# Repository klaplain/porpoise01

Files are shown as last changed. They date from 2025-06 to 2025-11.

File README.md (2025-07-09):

# UnderwaterAcoustics
This is the code required for the Underwater Acoustics STM32 Acquisition SubSystem that works with the Porpoise01 board and the Raspberry Pi

main.c contains the necessary code to acquire an analog signal sampling at about 700kHz and storing the result to a .DAT file that contains the analog values.  Although the file has a WAV file header, the values are 16 bit unsigned values so the DAT file needs to be post-processed to convert it to a WAV file.  This post-processing is done when saving to the raspberry pi.

*.ioc contains all the necessary CubeIDE configuration data

uw_acoust_client.py is the app that runs on the raspberry pi and controls the Seeed STM32 acquisition system

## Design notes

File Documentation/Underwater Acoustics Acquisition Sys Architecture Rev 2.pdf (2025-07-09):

The Underwater Acoustics Acquisition System is based on an STM32H7x board that is responsible for the hydrophone analog signal acquisition and storing the recorded values on an SD card on the STM board. The STM board is under the control of a Raspberry Pi that has a GUI which the operator uses to control the acquisition

The Raspberry Pi communicates commands to the STM32 using an SPI interface. The STM32 executes the requested command and, if required, returns data to the Raspberry Pi.

The STM32 board also has a serial port through which diagnostics messages are sent during normal operation

The User Interface looks like this and is served up by the Raspberry Pi using a Flask Server

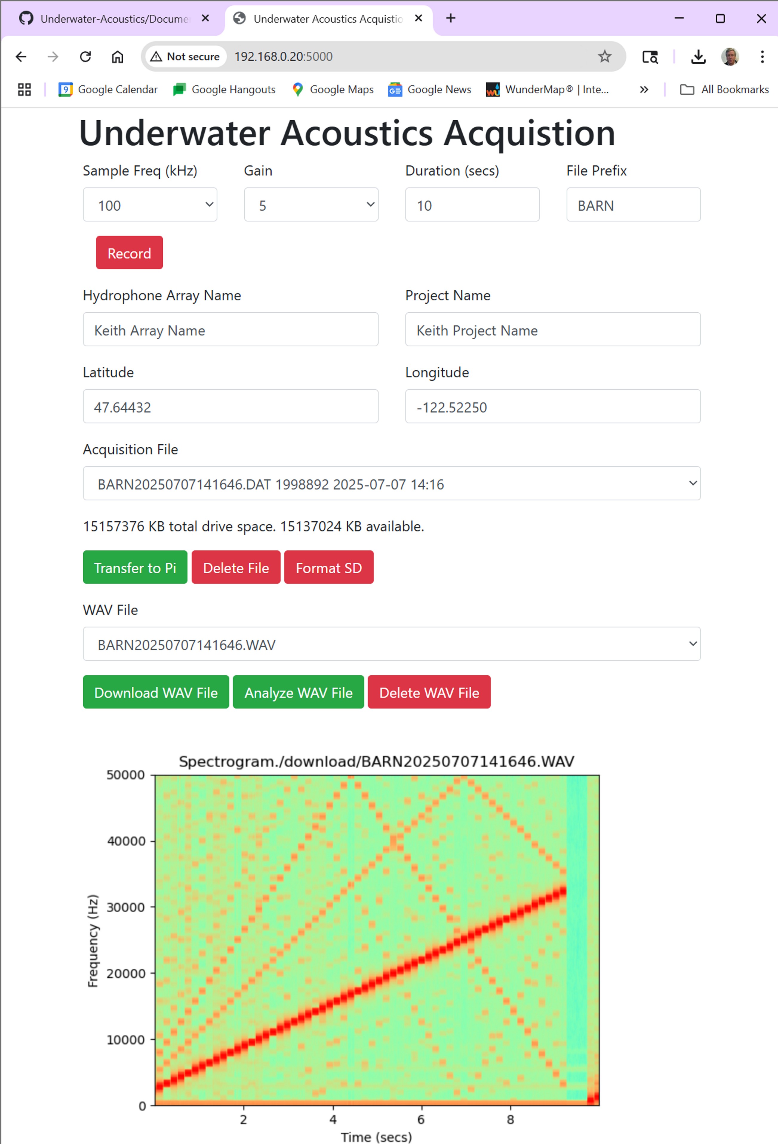
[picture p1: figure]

The user defines the parameters for the upcoming recording including duration, sampling frequency and gain.
The user can select from 7 different gain levels
The filename of the acquired data is the date and time with a file prefix chosen from the user interfac

When initially started, the STM32 mounts the SD. If the SD card cannot be mounted, a error message is sent to the STM32 diagnostics port

When the Record button is pressed, all parameters for the recording are sent from the Raspberry Pi to the STM32.
The Raspberry Pi also sends the latest date/time to the STM32 which the STM32 uses to set it's internal real time clock
The STM sets up the ADC, DMA and initiates data collection.
ADC data is captured using the 16 bit ADC on the STM32.
ADC data is captured continually with the completion of each ADC conversion initiating the next ADC conversion
Captured data is stored in memory that is organized as 16k samples. The memory is further subdivided into two halves (an upper and lower buffer). Initially, data is saved to the lower buffer and when the buffer is full, further data is saved to the upper buffer. At this time, the STM32 initiates the use of DMA to transfer the contents of the lower buffer to the SD card. This flip flop process continues until the end of the Duration.
At the end of the duration the STM32 closes the file and increments the "highest file number" counter
The STM32 also sets the date/time on the file

When the Transfer to Pi button is pressed, the Acquisition File selected from the dropdown list is moved from the STM32 SD Card to the Raspberry Pi. Data is transferred in large blocks that are sequentially requested by the Raspberry Pi which is always the Master of the SPI interface

# Underwater Acoustics Acquisition Sys Architecture and Design Rev 2

Sunday, October 1, 2023 1:38 PM

The DAT file format on the STM32 SD card is essentially a standard WAV file format with the exception that the analog values are stored as 16 bit unsigned integers. When the data is sent from the STM32 to the Raspberry Pi, the STM32 subtracts 0x8000 from the analog values to provide a file that has data values stored as 16 bit signed integers.
The Raspberry Pi opens the file in the file system
The Raspberry Pi is the Master for the SPI interface and to ensure it does not outpace the STM32, a BUSY handshake line is implemented such that the STM32 will tell the Raspberry Pi when it is busy and cannot accept a further SPI request. The Raspberry Pi only sends data requests when the STM32 is not busy. The BUSY line is implemented on PF3-D10 on the STM32. The BUSY line connects to GPIO 27 on the Raspberry Pi

The communication protocol between the STM and Raspberry Pi is shown in the PPT

Under normal operation the STM is waiting from commands from the Raspberry Pi. When the Raspberry Pi sends a command, it first takes the Chip Select low (SPI_NCS)

Analog signals received by the STM32 ADC must be between 0.5v and 3.0v

GPS Communications
Field | NMEA_buff | Structure | Description | Symbol | Example
1 | 0 | $GPGGA | Log header | | $GPGGA
2 | 1 | utc | UTC time status of position (hours/minutes/seconds/ decimal seconds) | hhmmss.ss | 202134
3 | 2 | lat | Latitude (DDmm.mm) | llll.ll | 5106.9847
4 | 3 | lat dir | Latitude direction (N = North, S = South) | a | N
5 | 4 | lon | Longitude (DDDmm.mm) | yyyyy.yy | 11402.2986
6 | 5 | lon dir | Longitude direction (E = East, W = West) | a | W
7 | 6 | quality | refer to Table: GPS Quality Indicators | x | 1
8 | 7 | # sats | Number of satellites in use. May be different to the number in view | xx | 10
9 | 8 | hdop | Horizontal dilution of precision | x.x | 1
10 | 9 | alt | Antenna altitude above/below mean sea level | x.x | 1062.22
11 | 10 | a-units | Units of antenna altitude (M = metres) | M | M
12 | 11 | undulation | Undulation - the relationship between the geoid and the WGS84 ellipsoid | x.x | -16.271
13 | 12 | u-units | Units of undulation (M = metres) | M | M
14 | 13 | age | Age of correction data (in seconds) | xx | (empty when no differential data is present)
15 | 14 | stn ID | Differential base station ID | xxxx | (empty when no differential data is present)
16 | 15 | *xx | Check sum | *hh | *48
17 | 16 | [CR][LF] | Sentence terminator | | [CR][LF]

GPS Quality Indicators
Indicator | Description
0 Fix not available or invalid 1 Single point
| Converging PPP (TerraStar-L)
2 Pseudorange differential
| Converged PPP (TerraStar-L)
| Converging PPP (TerraStar-C, TerraStar-C PRO, TerraStar-X)
4 RTK fixed ambiguity solution
5 RTK floating ambiguity solution
| Converged PPP (TerraStar-C, TerraStar-C PRO, TerraStar-X)
6 Dead reckoning mode
7 Manual input mode (fixed position)
8 Simulator mode
9 WAAS (SBAS)1

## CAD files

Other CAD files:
pcb/special_porpoise_first_fab/pi3b+_simplified.dxf

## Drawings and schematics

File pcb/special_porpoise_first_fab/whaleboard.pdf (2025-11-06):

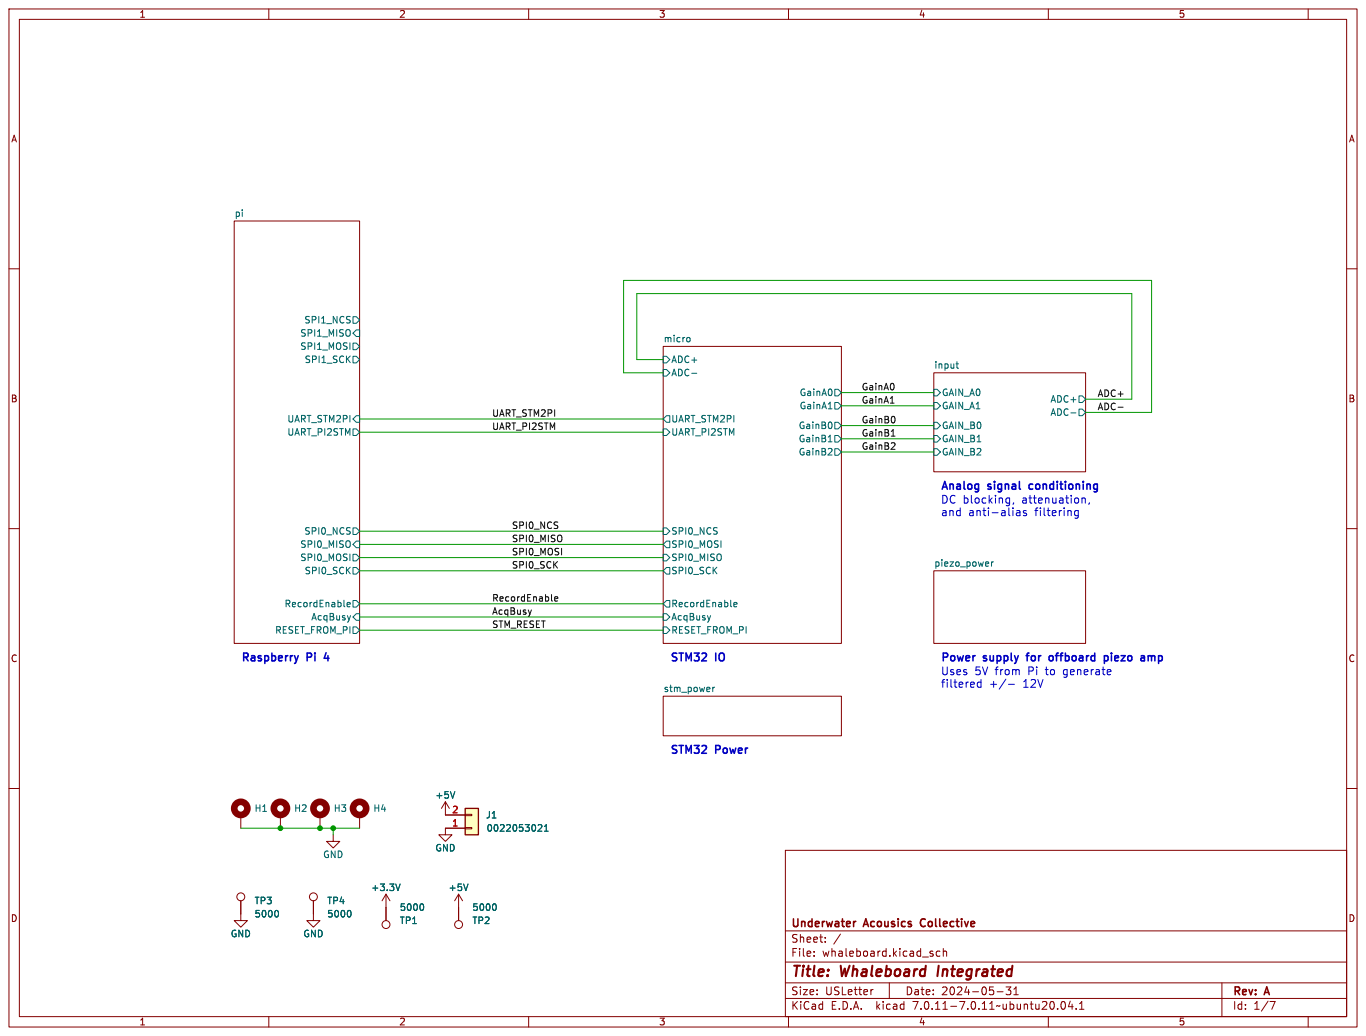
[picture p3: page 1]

File: whaleboard.kicad_sch Sheet: / Underwater Acousics Collective

Id: 1/7 Title: Whaleboard Integrated

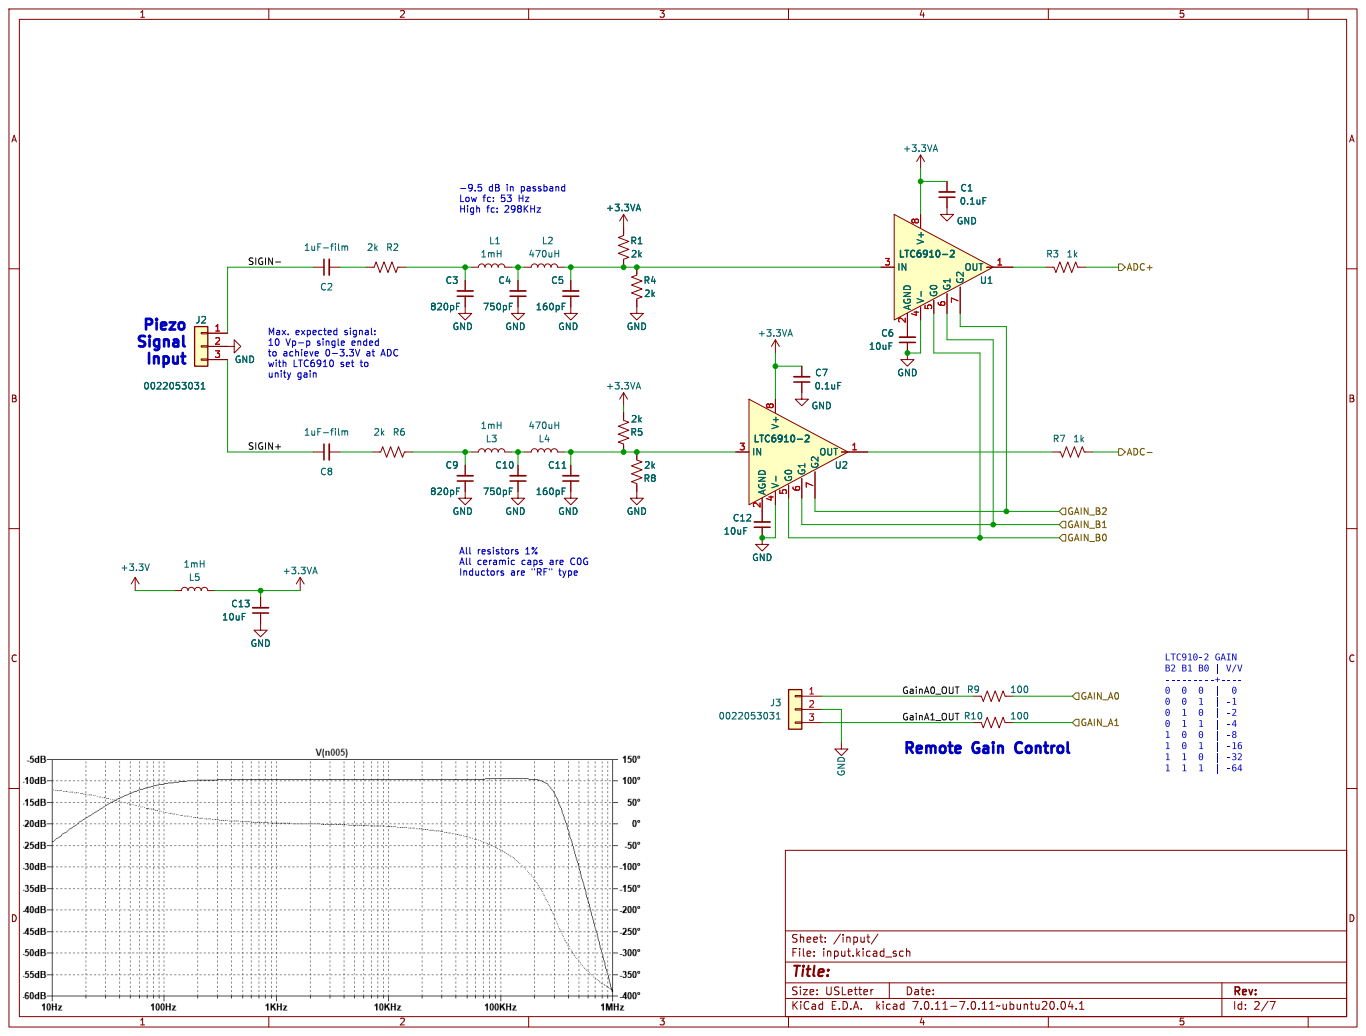
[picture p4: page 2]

Low fc: 53 Hz High fc: 298KHz Max. expected signal: 10 Vp-p single ended

All ceramic caps are C0G

Id: 2/7 Title: File: input.kicad_sch Sheet: /input/

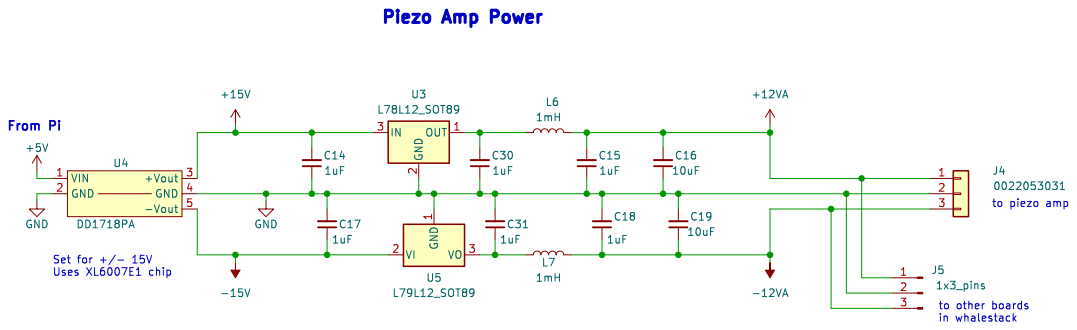
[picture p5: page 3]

Id: 3/7 Title: File: piezo_power.kicad_sch Sheet: /piezo_power/

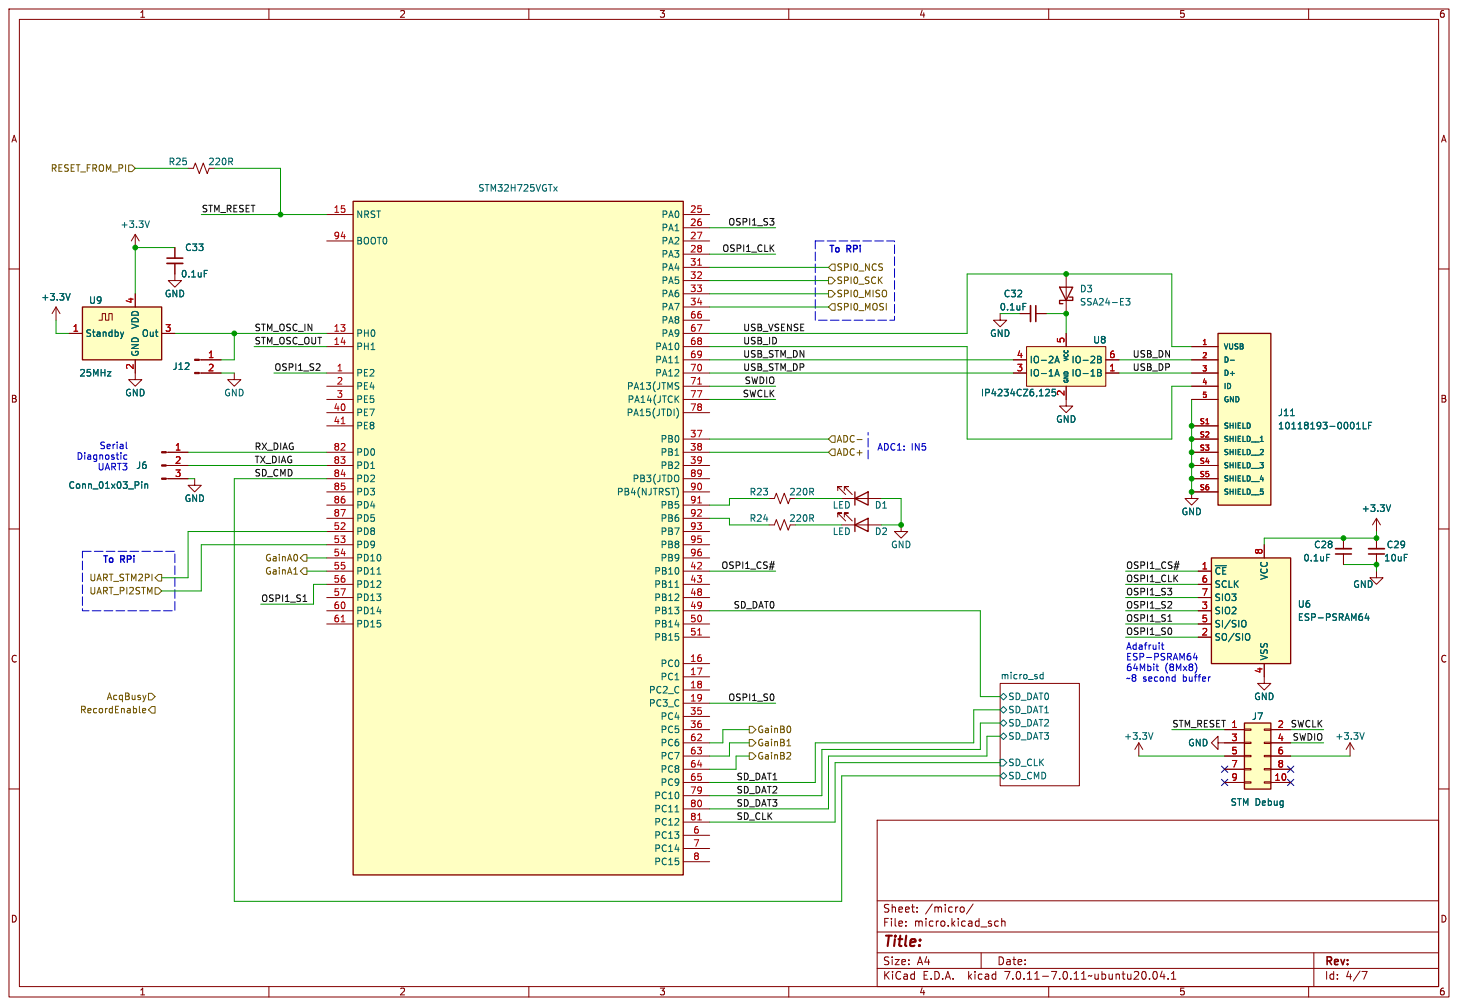
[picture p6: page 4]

4 SI/SIO 5 SCLK 6 SIO3 7 VCC

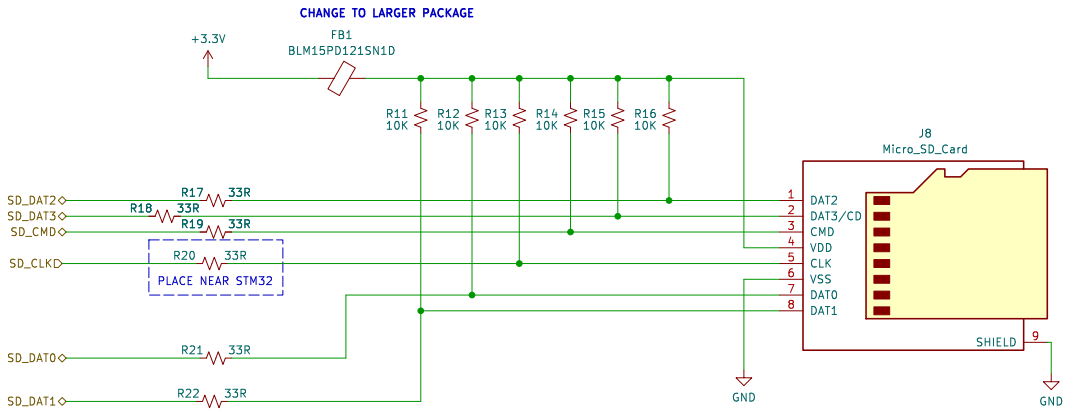
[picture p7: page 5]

Id: 5/7 Title: File: micro_sd.kicad_sch Sheet: /micro/micro_sd/

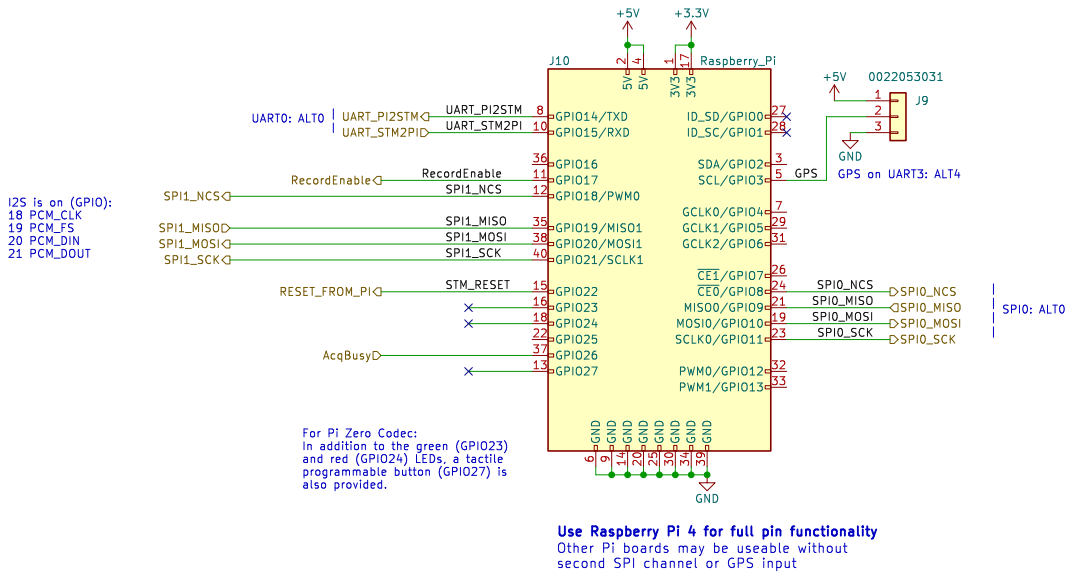
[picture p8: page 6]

SPI1_MOSI For Pi Zero Codec:

Id: 6/7 Title: File: pi.kicad_sch Sheet: /pi/ GND

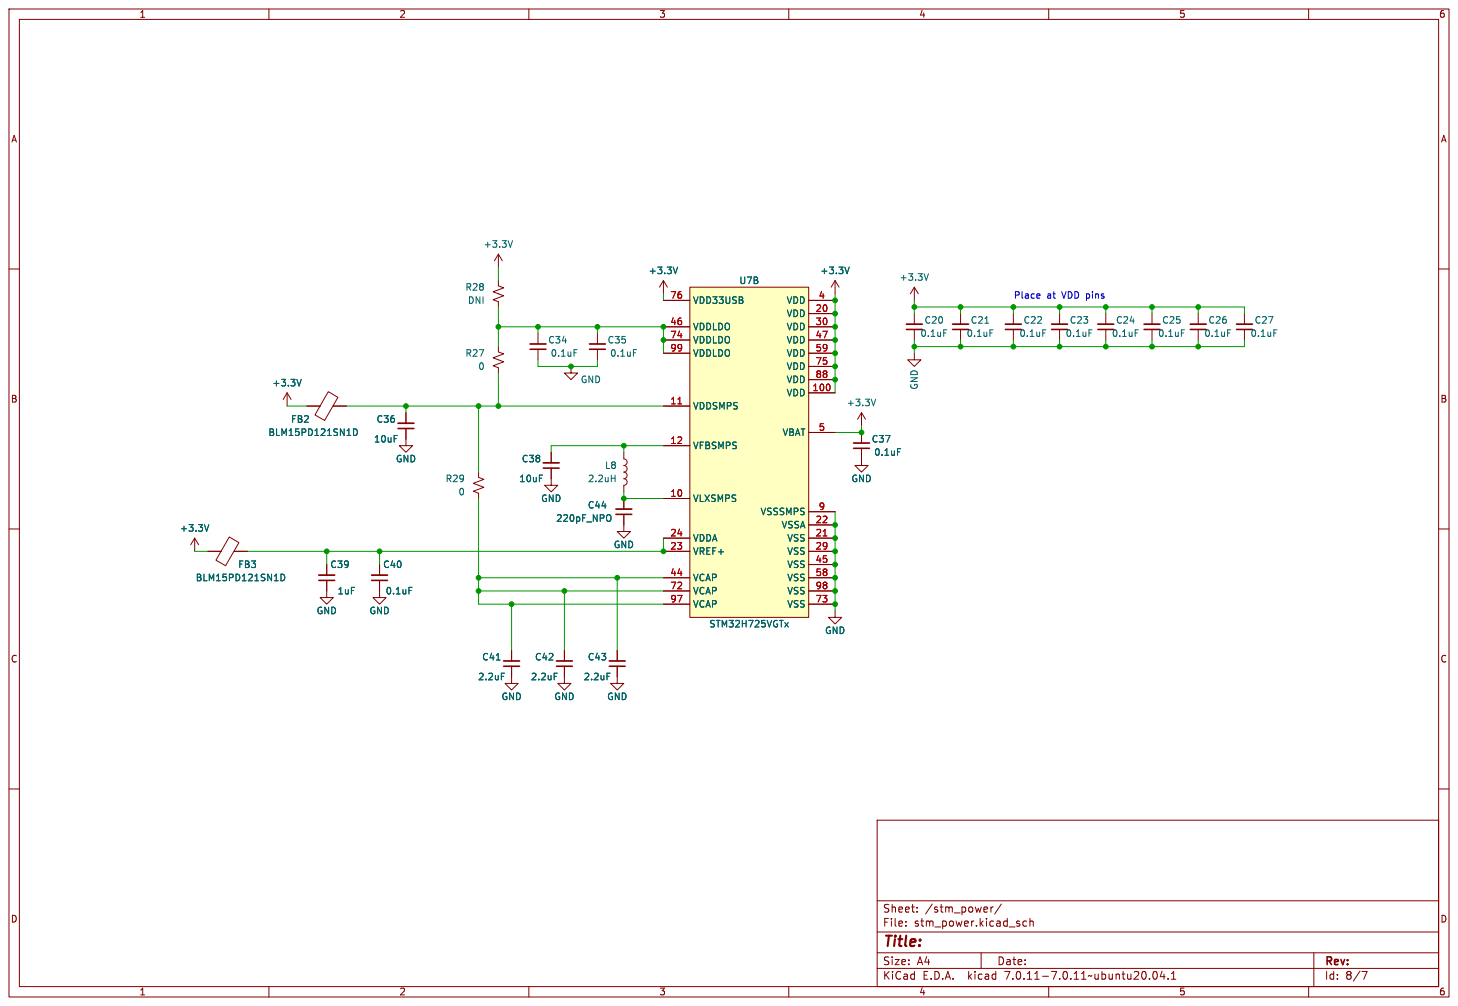
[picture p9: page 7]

0.1uF Place at VDD pins +3.3V U7B

Id: 8/7 Title: File: stm_power.kicad_sch Sheet: /stm_power/ C39

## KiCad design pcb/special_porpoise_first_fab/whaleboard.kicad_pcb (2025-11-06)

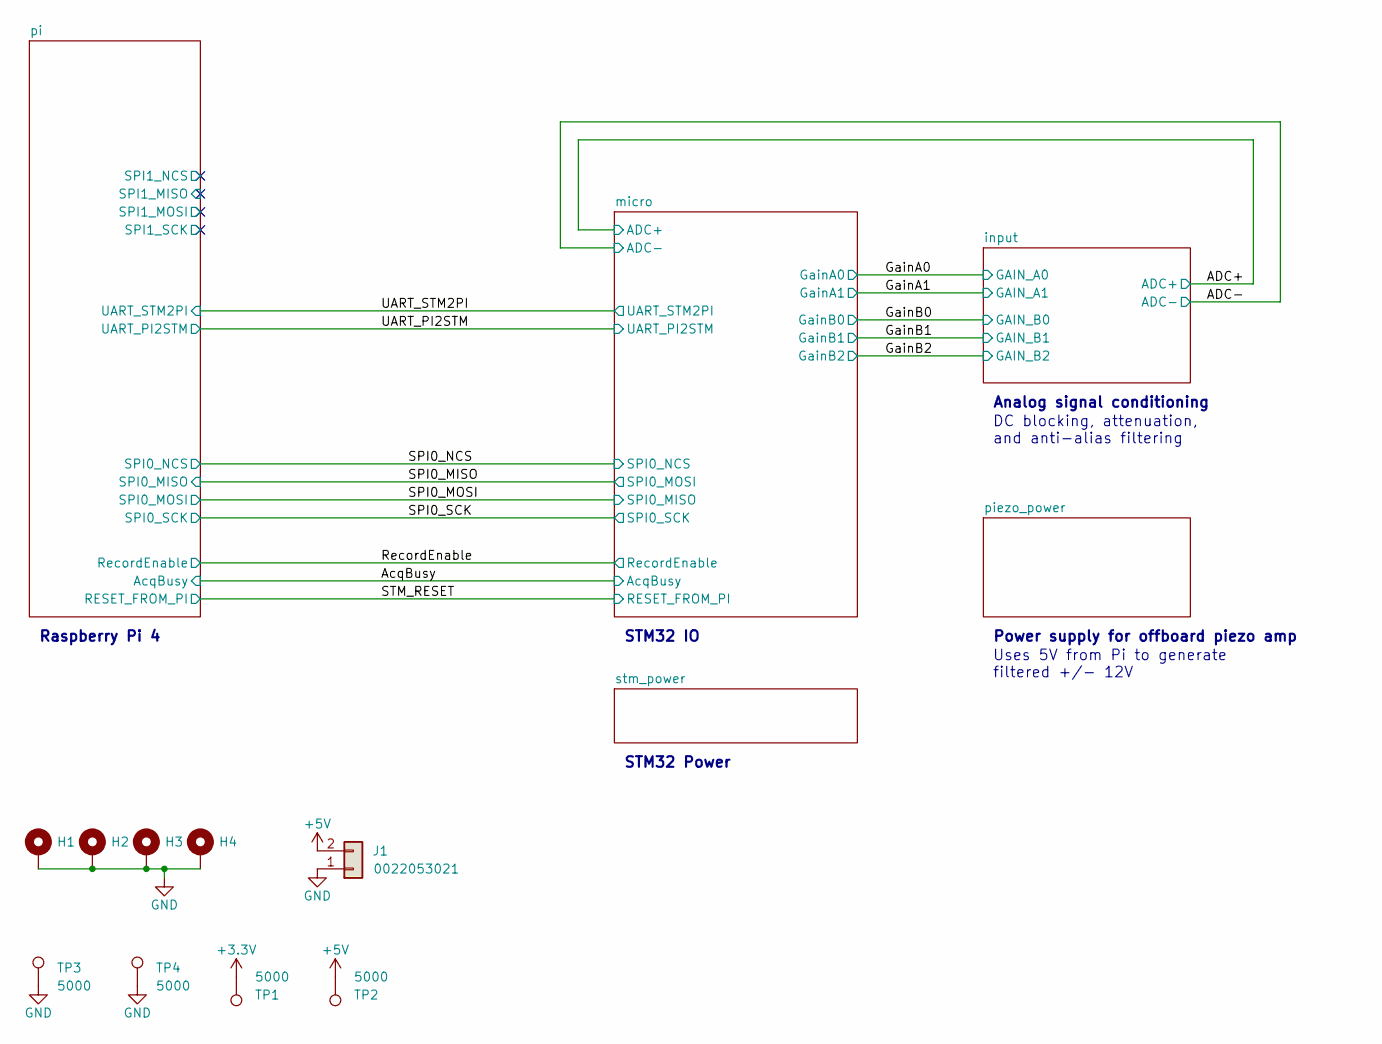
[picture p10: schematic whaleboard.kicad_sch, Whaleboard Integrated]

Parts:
H1, H2, H3, H4: MountingHole_Pad; MountingHole_2.7mm_Pad
J1: 0022053021; Molex_KK-254_AE-6410-02A_1x02_P2.54mm_Vertical; DIGI 900-0022053021-ND
TP1, TP2, TP3, TP4: 5000; TestPoint_Keystone_5000-5004_Miniature

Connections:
+3.3V: TP1.1; also elsewhere on the board
+5V: J1.2, TP2.1; also elsewhere on the board
GND: H1.1, H2.1, H3.1, H4.1, J1.1, TP3.1, TP4.1; also elsewhere on the board

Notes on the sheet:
Uses 5V from Pi to generate filtered +/- 12V
Analog signal conditioning
STM32 IO
STM32 Power
DC blocking, attenuation, and anti-alias filtering
Raspberry Pi 4
Power supply for offboard piezo amp

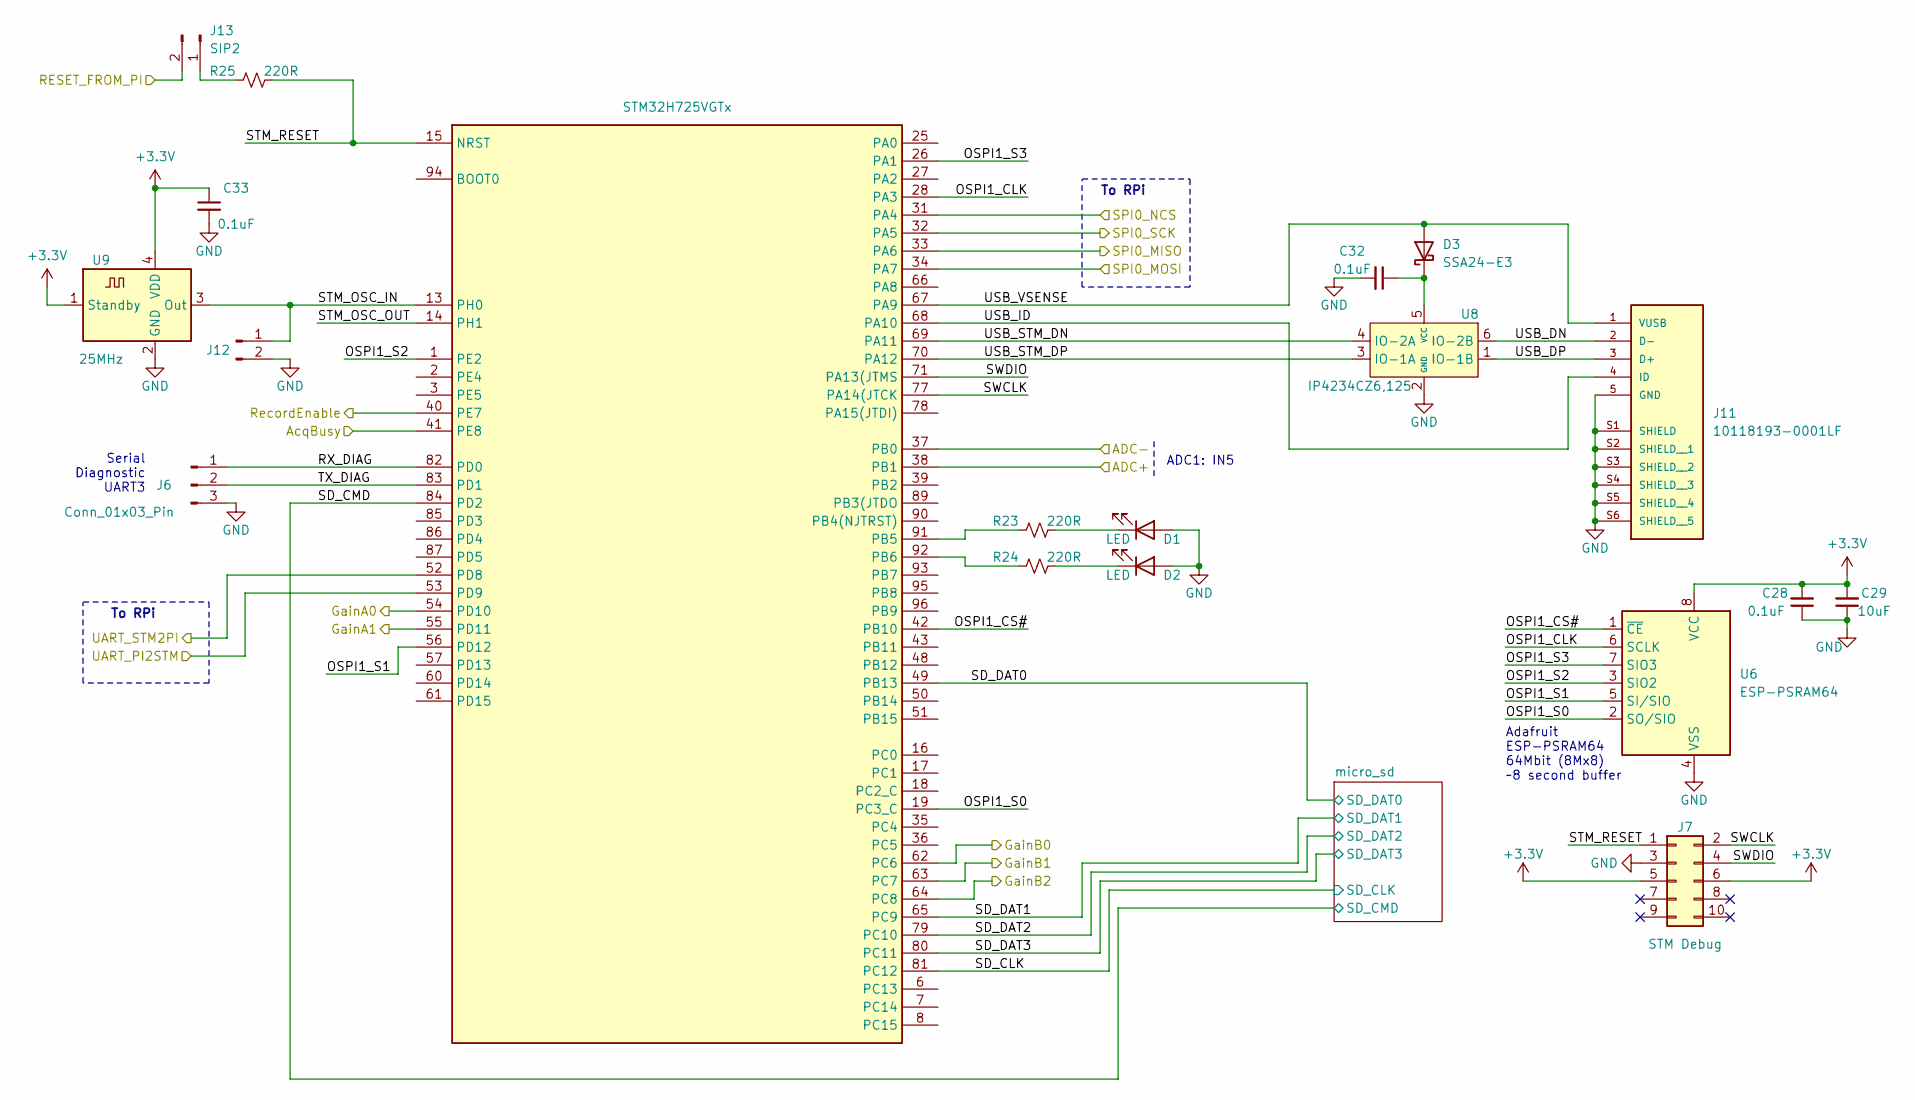
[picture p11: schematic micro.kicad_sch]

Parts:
C28, C32, C33: 0.1uF; C_0603_1608Metric; DIGI 1276-1000-1-ND
C29: 10uF; C_0805_2012Metric; DIGI 1276-1096-1-ND
D1, D2: LED; LED_0805_2012Metric; DIGI 3147-B1701UY--20D000214U1930CT-ND
D3: SSA24-E3; D_SMA; DIGI SSA24-E3/61TGICT-ND
J6: Conn_01x03_Pin; PinHeader_1x03_P2.54mm_Vertical
J7: STM Debug; PinSocket_2x05_P2.54mm_Vertical; DIGI S9194-ND
J11: 10118193-0001LF; AMPHENOL_10118193-0001LF; PARTREV E; DIGI 609-4616-1-ND
J12: Conn_01x02_Pin; PinHeader_1x02_P2.00mm_Vertical
J13: SIP2; PinHeader_1x02_P2.54mm_Vertical
R23, R24, R25: 220R; R_0603_1608Metric
U6: ESP-PSRAM64; SOIC-8_3.9x4.9mm_P1.27mm; DIGI 1528-4677-ND
U7: STM32H725VGTx; LQFP-100_14x14mm_P0.5mm
U8: IP4234CZ6,125; TSOP-6_1.65x3.05mm_P0.95mm; DIGI 1727-4717-1-ND
U9: 25MHz; Oscillator_SMD_Abracon_ASDMB-4Pin_2.5x2.0mm; DIGI 535-ATX-H12-F-25.000MHZ-G100-TCT-ND

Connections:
+3.3V: C28.2, C29.2, C33.1, J7.5, J7.6, U6.8 (VCC), U9.1 (Standby), U9.4 (VDD); also elsewhere on the board
/ADC+: U7.38 (PB1); also elsewhere on the board
/ADC-: U7.37 (PB0); also elsewhere on the board
/AcqBusy: U7.41 (PE8); also elsewhere on the board
/GainA0: U7.54 (PD10); also elsewhere on the board
/GainA1: U7.55 (PD11); also elsewhere on the board
/GainB0: U7.62 (PC6); also elsewhere on the board
/GainB1: U7.63 (PC7); also elsewhere on the board
/GainB2: U7.64 (PC8); also elsewhere on the board
/RecordEnable: U7.40 (PE7); also elsewhere on the board
/SPI0_MISO: U7.34 (PA7); also elsewhere on the board
/SPI0_MOSI: U7.33 (PA6); also elsewhere on the board
/SPI0_NCS: U7.31 (PA4); also elsewhere on the board
/SPI0_SCK: U7.32 (PA5); also elsewhere on the board
/STM_RESET: J13.2; also elsewhere on the board
/UART_PI2STM: U7.53 (PD9); also elsewhere on the board
/UART_STM2PI: U7.52 (PD8); also elsewhere on the board
/micro/OSPI1_CLK: U6.6 (SCLK), U7.28 (PA3)
/micro/OSPI1_CS#: U6.1 (~CE), U7.42 (PB10)
/micro/OSPI1_S0: U6.2 (SO/SIO), U7.19 (PC3_C)
/micro/OSPI1_S1: U6.5 (SI/SIO), U7.56 (PD12)
/micro/OSPI1_S2: U6.3 (SIO2), U7.1 (PE2)
/micro/OSPI1_S3: U6.7 (SIO3), U7.26 (PA1)
/micro/RX_DIAG: J6.1, U7.82 (PD0)
/micro/SD_CLK: U7.81 (PC12); also elsewhere on the board
/micro/SD_CMD: U7.84 (PD2); also elsewhere on the board
/micro/SD_DAT0: U7.49 (PB13); also elsewhere on the board
/micro/SD_DAT1: U7.65 (PC9); also elsewhere on the board
/micro/SD_DAT2: U7.79 (PC10); also elsewhere on the board
/micro/SD_DAT3: U7.80 (PC11); also elsewhere on the board
/micro/STM_OSC_IN: J12.1, U7.13 (PH0), U9.3 (Out)
/micro/STM_OSC_OUT: U7.14 (PH1)
/micro/STM_RESET: J7.1, R25.2, U7.15 (NRST)
/micro/SWCLK: J7.2, U7.77 (PA14(JTCK)
/micro/SWDIO: J7.4, U7.71 (PA13(JTMS)
/micro/TX_DIAG: J6.2, U7.83 (PD1)
/micro/USB_DN: J11.2 (D-), U8.6 (IO-2B)
/micro/USB_DP: J11.3 (D+), U8.1 (IO-1B)
/micro/USB_ID: J11.4 (ID), U7.68 (PA10)
/micro/USB_STM_DN: U7.69 (PA11), U8.4 (IO-2A)
/micro/USB_STM_DP: U7.70 (PA12), U8.3 (IO-1A)
/micro/USB_VSENSE: D3.2 (A), J11.1 (VUSB), U7.67 (PA9)
GND: C28.1, C29.1, C32.2, C33.2, D1.2 (A), D2.2 (A), J6.3, J7.3, J11.5 (GND), J11.S1 (SHIELD), J11.S2 (SHIELD__1), J11.S3 (SHIELD__2), J11.S4 (SHIELD__3), J11.S5 (SHIELD__4), J11.S6 (SHIELD__5), J12.2, U6.4 (VSS), U8.2 (GND), U9.2 (GND); also elsewhere on the board
unnamed: D1.1 (K), R23.2
unnamed: D2.1 (K), R24.2
unnamed: C32.1, D3.1 (K), U8.5 (VCC)
unnamed: J13.1, R25.1
unnamed: R23.1, U7.91 (PB5)
unnamed: R24.1, U7.92 (PB6)

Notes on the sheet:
Adafruit ESP-PSRAM64 64Mbit (8Mx8) ~8 second buffer
Serial Diagnostic UART3
ADC1: IN5
To RPi

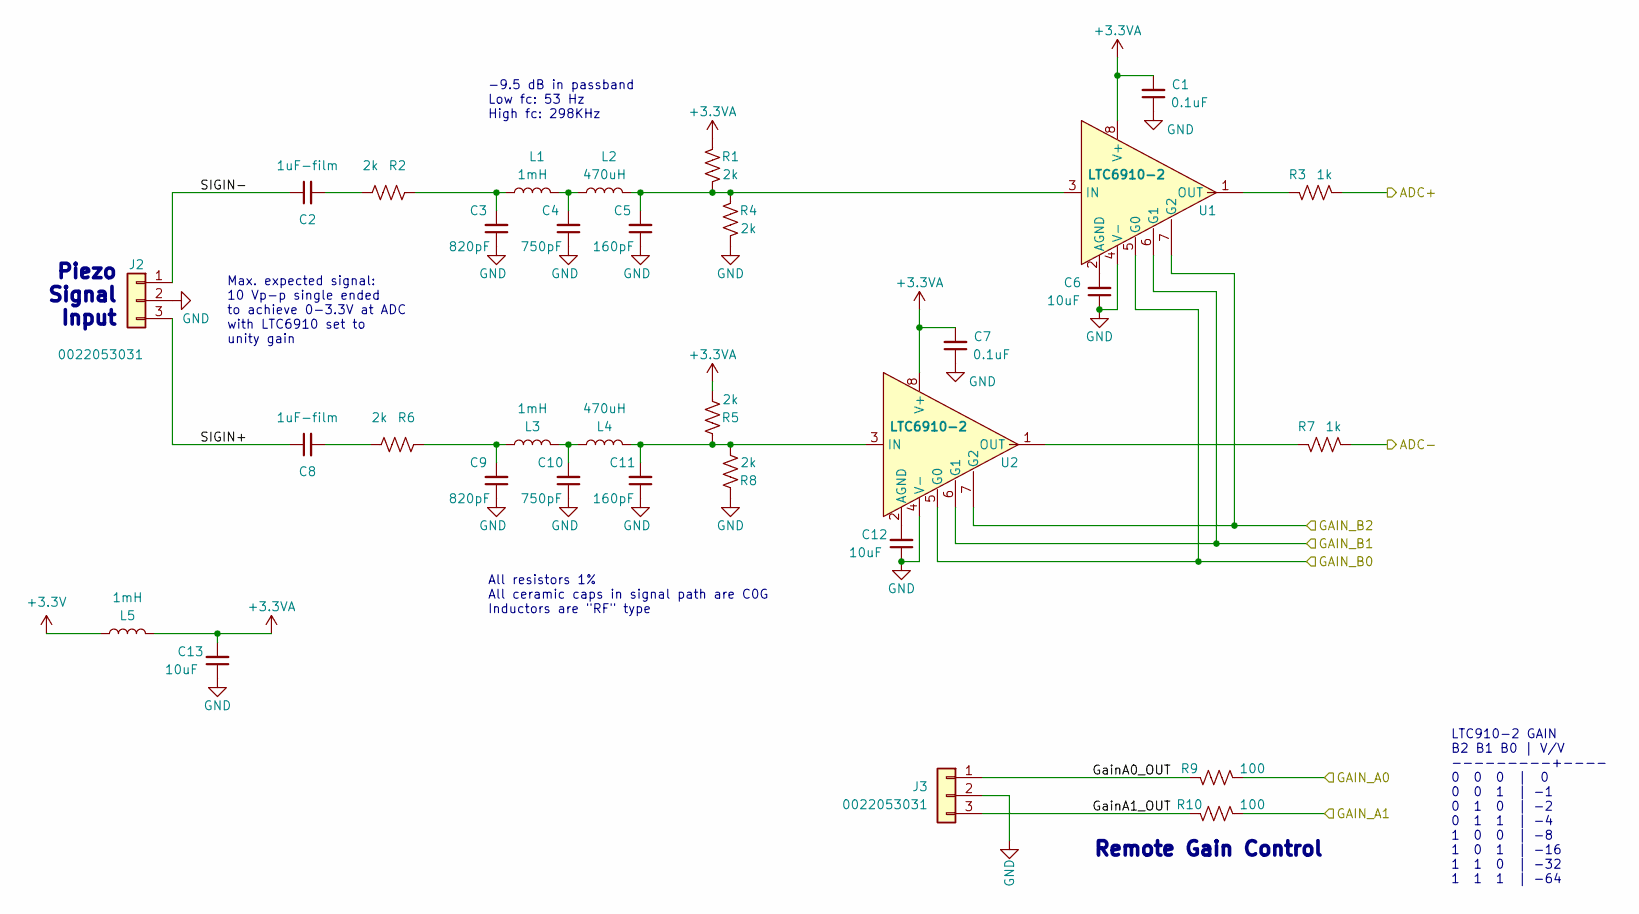
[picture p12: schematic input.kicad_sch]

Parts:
C1, C7: 0.1uF; C_0603_1608Metric; DIGI 1276-1000-1-ND
C2, C8: 1uF-film; C_2220_5750Metric; DIGI 399-LDECD4100MA0N00CT-ND
C3, C9: 820pF; C_1206_3216Metric; DIGI 478-KGM31BCG2A821JTCT-ND
C4, C10: 750pF; C_1206_3216Metric; DIGI 399-14711-1-ND
C5, C11: 160pF; C_0603_1608Metric; DIGI 399-15367-1-ND
C6, C12, C13: 10uF; C_0805_2012Metric; DIGI 1276-1096-1-ND
J2, J3: 0022053031; CONN_A-7478-03A_MOL; DIGI WM4301-ND
L1, L3, L5: 1mH; L_1812_4532Metric_Pad1.30x3.40mm_HandSolder; DIGI CM453232-102JLCT-ND
L2, L4: 470uH; L_1812_4532Metric_Pad1.30x3.40mm_HandSolder; DIGI 118-CM453232-471JLCT-ND
R1, R2, R4, R5, R6, R8: 2k; R_0603_1608Metric; DIGI RC0603FR-072KL
R3, R7: 1k; R_0603_1608Metric; DIGI 311-1.00KHRCT-ND
R9, R10: 100; R_0603_1608Metric; DIGI 311-100HRCT-ND
U1, U2: LTC6910-2; TSOT-23-8; DIGI 161-LTC6910-2ITS8#TRPBFCT-ND

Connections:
+3.3V: L5.1; also elsewhere on the board
+3.3VA: C1.2, C7.2, C13.2, L5.2, R1.2, R5.1, U1.8 (V+), U2.8 (V+)
/ADC+: R3.1; also elsewhere on the board
/ADC-: R7.1; also elsewhere on the board
/GainA0: R9.1; also elsewhere on the board
/GainA1: R10.1; also elsewhere on the board
/GainB0: U1.5 (G0), U2.5 (G0); also elsewhere on the board
/GainB1: U1.6 (G1), U2.6 (G1); also elsewhere on the board
/GainB2: U1.7 (G2), U2.7 (G2); also elsewhere on the board
/input/GainA0_OUT: J3.1, R9.2
/input/GainA1_OUT: J3.3, R10.2
/input/SIGIN+: C8.1, J2.3
/input/SIGIN-: C2.1, J2.1
GND: C1.1, C3.1, C4.1, C5.1, C6.1, C7.1, C9.1, C10.1, C11.1, C12.1, C13.1, J2.2, J3.2, R4.1, R8.2, U1.4 (V-), U2.4 (V-); also elsewhere on the board
unnamed: C2.2, R2.1
unnamed: C3.2, L1.1, R2.2
unnamed: C4.2, L1.2, L2.1
unnamed: C8.2, R6.1
unnamed: C9.2, L3.1, R6.2
unnamed: C10.2, L3.2, L4.1
unnamed: C6.2, U1.2 (AGND)
unnamed: C5.2, L2.2, R1.1, R4.2, U1.3 (IN)
unnamed: R3.2, U1.1 (OUT)
unnamed: C12.2, U2.2 (AGND)
unnamed: C11.2, L4.2, R5.2, R8.1, U2.3 (IN)
unnamed: R7.2, U2.1 (OUT)

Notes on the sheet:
All resistors 1% All ceramic caps in signal path are C0G Inductors are "RF" type
-9.5 dB in passband Low fc: 53 Hz High fc: 298KHz
Max. expected signal: 10 Vp-p single ended to achieve 0-3.3V at ADC with LTC6910 set to unity gain
LTC910-2 GAIN B2 B1 B0 | V/V ---------+---- 0 0 0 | 0 0 0 1 | -1 0 1 0 | -2 0 1 1 | -4 1 0 0 | -8 1 0 1 | -16 1 1 0 | -32 1 1 1 | -64
Piezo Signal Input
Remote Gain Control

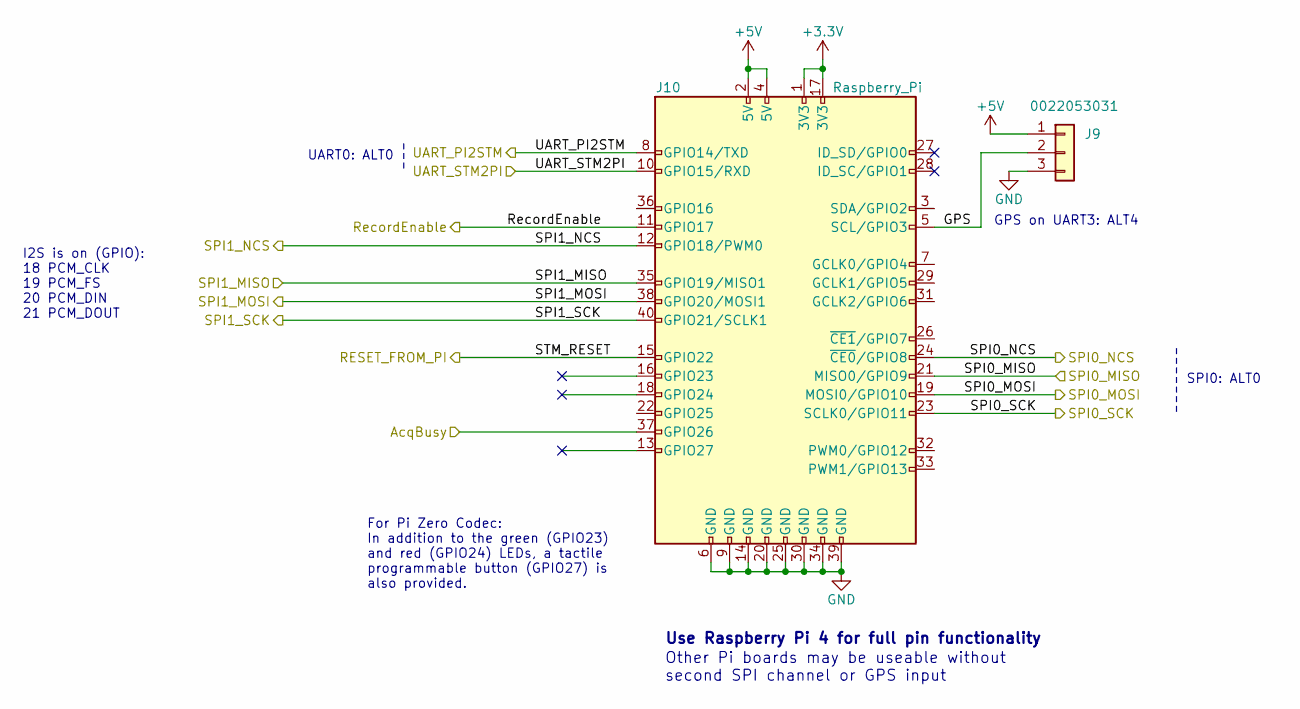
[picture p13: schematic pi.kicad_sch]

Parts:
J9: 0022053031; CONN_A-7478-03A_MOL; DIGI WM4301-ND
J10: Raspberry_Pi; PinSocket_2x20_P2.54mm_Vertical; DIGI 1568-PRT-16763-ND

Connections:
+3.3V: J10.1 (3V3), J10.17 (3V3); also elsewhere on the board
+5V: J9.1, J10.2 (5V), J10.4 (5V); also elsewhere on the board
/AcqBusy: J10.37 (GPIO26); also elsewhere on the board
/RecordEnable: J10.11 (GPIO17); also elsewhere on the board
/SPI0_MISO: J10.21 (MISO0/GPIO9); also elsewhere on the board
/SPI0_MOSI: J10.19 (MOSI0/GPIO10); also elsewhere on the board
/SPI0_NCS: J10.24 (~CE0/GPIO8); also elsewhere on the board
/SPI0_SCK: J10.23 (SCLK0/GPIO11); also elsewhere on the board
/STM_RESET: J10.15 (GPIO22); also elsewhere on the board
/UART_PI2STM: J10.8 (GPIO14/TXD); also elsewhere on the board
/UART_STM2PI: J10.10 (GPIO15/RXD); also elsewhere on the board
/pi/GPS: J9.2, J10.5 (SCL/GPIO3)
/pi/SPI1_MISO: J10.35 (GPIO19/MISO1)
/pi/SPI1_MOSI: J10.38 (GPIO20/MOSI1)
/pi/SPI1_NCS: J10.12 (GPIO18/PWM0)
/pi/SPI1_SCK: J10.40 (GPIO21/SCLK1)
GND: J9.3, J10.6 (GND), J10.9 (GND), J10.14 (GND), J10.20 (GND), J10.25 (GND), J10.30 (GND), J10.34 (GND), J10.39 (GND); also elsewhere on the board

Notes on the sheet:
Other Pi boards may be useable without second SPI channel or GPS input
Use Raspberry Pi 4 for full pin functionality
SPI0: ALT0
I2S is on (GPIO): 18 PCM_CLK 19 PCM_FS 20 PCM_DIN 21 PCM_DOUT
UART0: ALT0
GPS on UART3: ALT4
For Pi Zero Codec: In addition to the green (GPIO23) and red (GPIO24) LEDs, a tactile programmable button (GPIO27) is also provided.

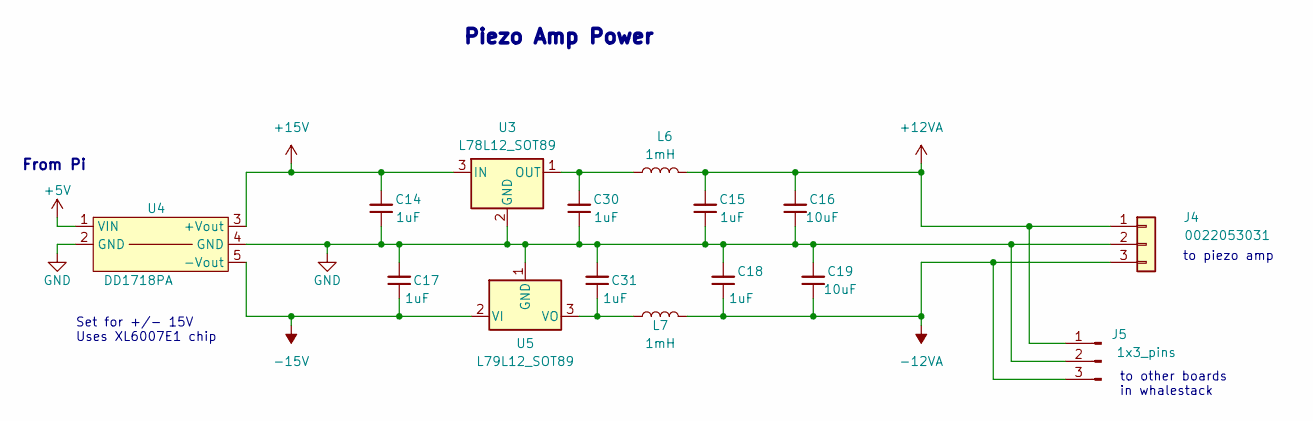
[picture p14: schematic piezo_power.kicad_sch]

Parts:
C14, C15, C17, C18, C30, C31: 1uF; C_0603_1608Metric; DIGI 1276-1102-1-ND
C16, C19: 10uF; C_0805_2012Metric; DIGI 1276-1096-1-ND
J4: 0022053031; CONN_A-7478-03A_MOL; DIGI WM4301-ND
J5: 1x3_pins; PinHeader_1x03_P2.54mm_Vertical
L6, L7: 1mH; L_1812_4532Metric_Pad1.30x3.40mm_HandSolder; DIGI CM453232-102JLCT-ND
U3: L78L12_SOT89; SOT-89-3; DIGI 497-1195-1-ND
U4: DD1718PA
U5: L79L12_SOT89; SOT-89-3; DIGI 497-7301-1-ND

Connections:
+5V: U4.1 (VIN); also elsewhere on the board
+12VA: C15.2, C16.2, J4.1, J5.1, L6.2
+15V: C14.2, U3.3 (IN), U4.3 (+Vout)
-12VA: C18.1, C19.1, J4.3, J5.3, L7.2
-15V: C17.1, U4.5 (-Vout), U5.2 (VI)
GND: C14.1, C15.1, C16.1, C17.2, C18.2, C19.2, C30.1, C31.2, J4.2, J5.2, U3.2 (GND), U4.2 (GND), U4.4 (GND), U5.1 (GND); also elsewhere on the board
unnamed: C30.2, L6.1, U3.1 (OUT)
unnamed: C31.1, L7.1, U5.3 (VO)

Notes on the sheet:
From Pi
to piezo amp
Piezo Amp Power
Set for +/- 15V Uses XL6007E1 chip
to other boards in whalestack

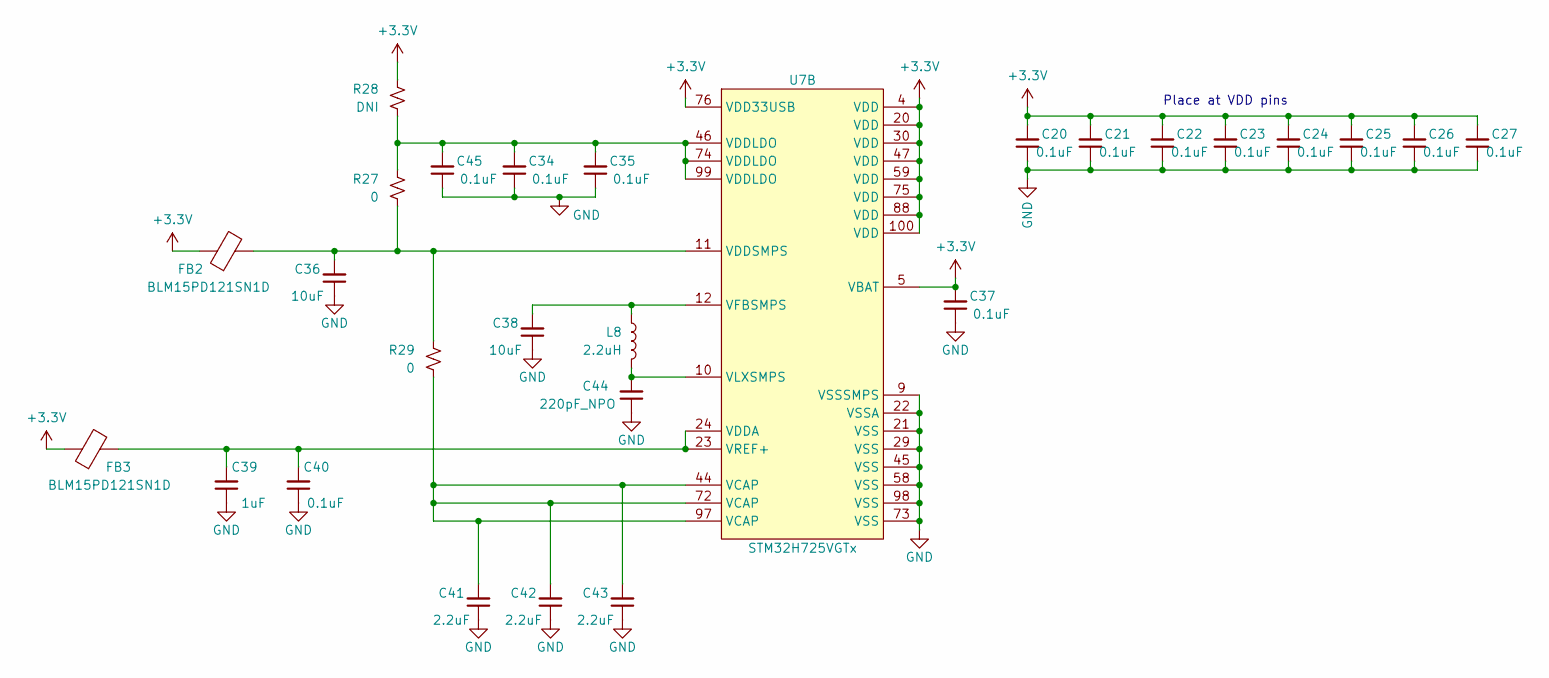
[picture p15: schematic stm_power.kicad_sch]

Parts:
C20, C21, C22, C23, C24, C25, C26, C27, C34, C35, C37, C40, C45: 0.1uF; C_0603_1608Metric; DIGI 1276-1000-1-ND
C36, C38: 10uF; C_0805_2012Metric; DIGI 1276-1096-1-ND
C39: 1uF; C_0603_1608Metric; DIGI 1276-1102-1-ND
C41, C42, C43: 2.2uF; C_0805_2012Metric; DIGI 1276-1763-1-ND
C44: 220pF_NPO; C_0603_1608Metric; DIGI 1276-1008-1-ND
FB2, FB3: BLM15PD121SN1D; C_0402_1005Metric_Pad0.74x0.62mm_HandSolder; DIGI 490-5203-1-ND
L8: 2.2uH; L_1008_2520Metric; DIGI 490-5114-1-ND
R27, R29: 0; R_0402_1005Metric_Pad0.72x0.64mm_HandSolder
R28: DNI; R_0402_1005Metric_Pad0.72x0.64mm_HandSolder
U7: STM32H725VGTx; LQFP-100_14x14mm_P0.5mm

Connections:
+3.3V: C20.2, C21.2, C22.2, C23.2, C24.2, C25.2, C26.2, C27.2, C37.2, FB2.1, FB3.1, R28.1, U7.4 (VDD), U7.5 (VBAT), U7.20 (VDD), U7.30 (VDD), U7.47 (VDD), U7.59 (VDD), U7.75 (VDD), U7.76 (VDD33USB), U7.88 (VDD), U7.100 (VDD); also elsewhere on the board
GND: C20.1, C21.1, C22.1, C23.1, C24.1, C25.1, C26.1, C27.1, C34.1, C35.1, C36.1, C37.1, C38.1, C39.1, C40.1, C41.1, C42.1, C43.1, C44.1, C45.1, U7.9 (VSSSMPS), U7.21 (VSS), U7.22 (VSSA), U7.29 (VSS), U7.45 (VSS), U7.58 (VSS), U7.73 (VSS), U7.98 (VSS); also elsewhere on the board
unnamed: C34.2, C35.2, C45.2, R27.1, R28.2, U7.46 (VDDLDO), U7.74 (VDDLDO), U7.99 (VDDLDO)
unnamed: C41.2, C42.2, C43.2, R29.2, U7.44 (VCAP), U7.72 (VCAP), U7.97 (VCAP)
unnamed: C39.2, C40.2, FB3.2, U7.23 (VREF+), U7.24 (VDDA)
unnamed: C36.2, FB2.2, R27.2, R29.1, U7.11 (VDDSMPS)
unnamed: C38.2, L8.2, U7.12 (VFBSMPS)
unnamed: C44.2, L8.1, U7.10 (VLXSMPS)

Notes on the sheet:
Place at VDD pins

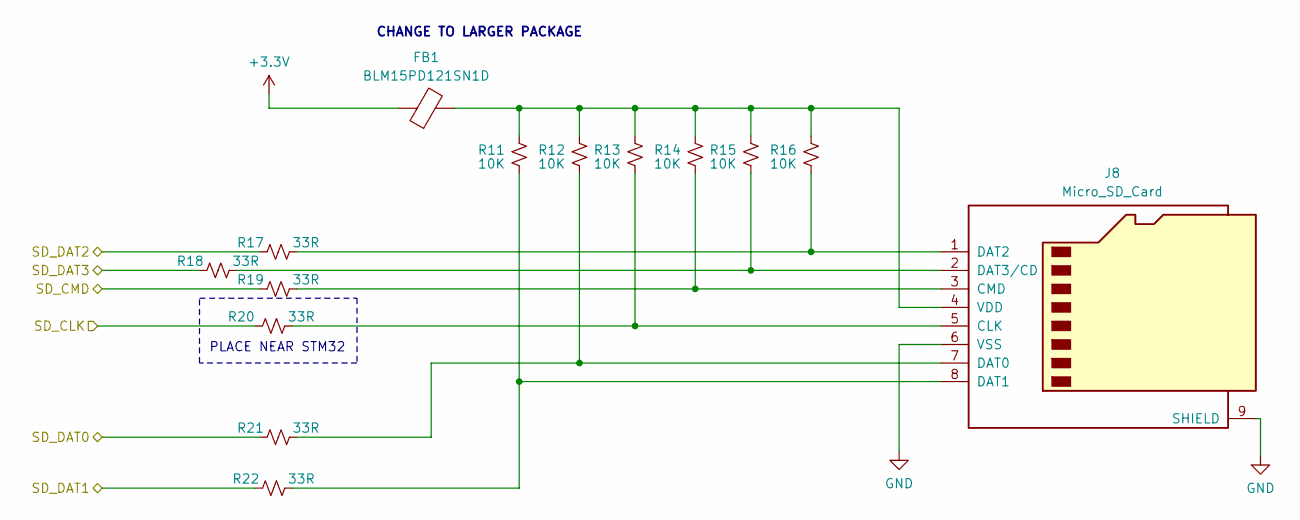
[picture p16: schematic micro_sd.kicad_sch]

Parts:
FB1: BLM15PD121SN1D; C_0402_1005Metric_Pad0.74x0.62mm_HandSolder; DIGI 490-5203-1-ND
J8: Micro_SD_Card; MOLEX_47219-2001; DIGI WM6698CT-ND
R11, R12, R13, R14, R15, R16: 10K; R_0603_1608Metric; DIGI 311-10.0KHRCT-ND
R17, R18, R19, R20, R21, R22: 33R; R_0603_1608Metric; DIGI 13-RC0603FR-1333RLCT-ND

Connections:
+3.3V: FB1.1; also elsewhere on the board
/micro/SD_CLK: R20.1; also elsewhere on the board
/micro/SD_CMD: R19.1; also elsewhere on the board
/micro/SD_DAT0: R21.1; also elsewhere on the board
/micro/SD_DAT1: R22.1; also elsewhere on the board
/micro/SD_DAT2: R17.1; also elsewhere on the board
/micro/SD_DAT3: R18.1; also elsewhere on the board
GND: J8.6 (VSS), J8.9 (SHIELD); also elsewhere on the board
unnamed: J8.5 (CLK), R13.1, R20.2
unnamed: J8.3 (CMD), R14.1, R19.2
unnamed: J8.7 (DAT0), R12.1, R21.2
unnamed: J8.8 (DAT1), R11.1, R22.2
unnamed: J8.1 (DAT2), R16.1, R17.2
unnamed: J8.2 (DAT3/CD), R15.1, R18.2
unnamed: FB1.2, J8.4 (VDD), R11.2, R12.2, R13.2, R14.2, R15.2, R16.2

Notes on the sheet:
CHANGE TO LARGER PACKAGE
PLACE NEAR STM32

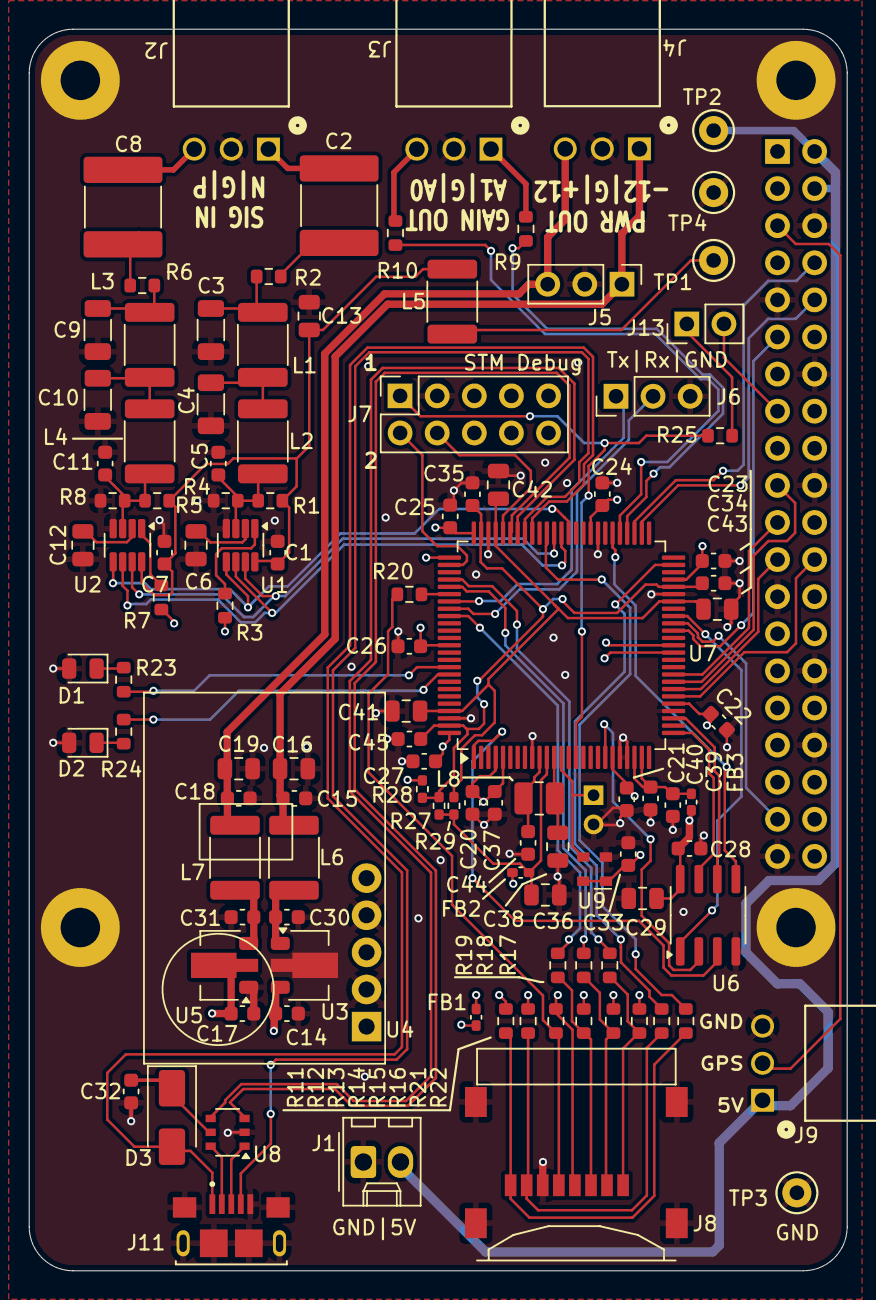
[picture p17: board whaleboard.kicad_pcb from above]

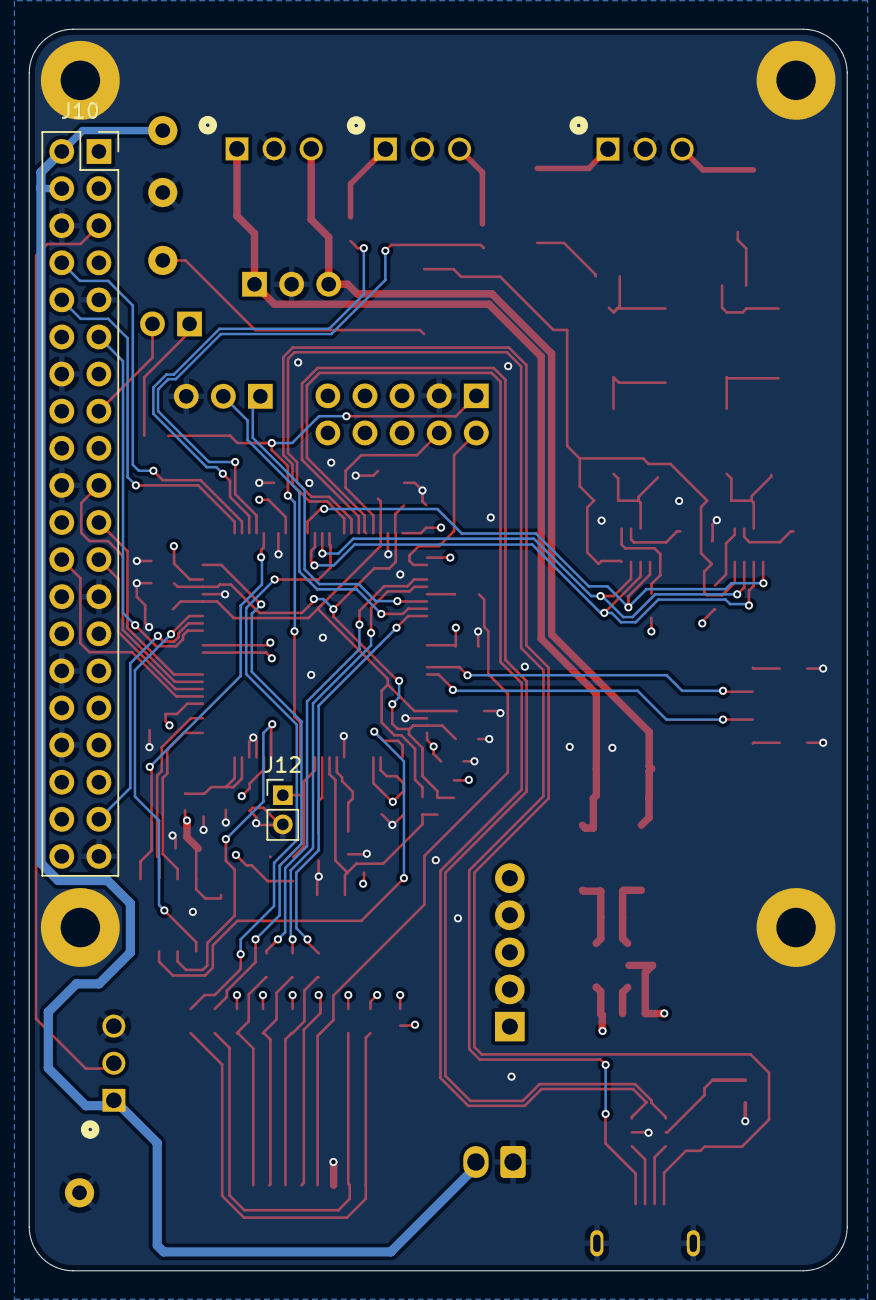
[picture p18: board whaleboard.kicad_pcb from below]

Board: 4 copper layers, 56.0 x 85.0 mm, 117 parts (2 on the bottom side), 86 nets.

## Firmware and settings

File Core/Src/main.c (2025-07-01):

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
/* Includes ------------------------------------------------------------------*/
#include "main.h"
#include "fatfs.h"

/* USER CODE BEGIN Includes */
#include "stdio.h"
#include "string.h"
#include "wav.h"
/* USER CODE END Includes */

/* USER CODE BEGIN PD */
/* ADC -----------------------------------------------------------------------*/
#define ADCBUFLEN 32768
#define BUFFER_FULL 1
#define BUFFER_EMPTY 0
#define DATABLOCK_SIZE 4096   // For transferring data to and from raspi
#define MAX_LENGTH_FILENAME 250

/* USER CODE END PD */

ADC_HandleTypeDef hadc1;
DMA_HandleTypeDef hdma_adc1;

RTC_HandleTypeDef hrtc;

SD_HandleTypeDef hsd1;

SPI_HandleTypeDef hspi6;

UART_HandleTypeDef huart4;
UART_HandleTypeDef huart3;

MDMA_HandleTypeDef hmdma_mdma_channel0_dma1_stream0_tc_0;
/* USER CODE BEGIN PV */
/* ADC Variables--------------------------------------------------------------*/
uint16_t adc_buf[ADCBUFLEN];
uint16_t adc_lower_status = BUFFER_EMPTY;
uint16_t adc_upper_status = BUFFER_EMPTY;
uint32_t millisecs_to_record=0;
uint32_t end_acq_ms;
uint32_t bytes_written=0;
uint32_t bytes_read=0;
uint32_t total_bytes_written=0;
uint32_t total_blocks_written=0;
uint32_t read_value=0;
uint32_t adcbuf_index=0;

uint16_t max_save_time_ms;
uint16_t start_time_ms,ms_taken;
int ADC_overrun =0; // set as FALSE
int overrun_count;

/* SD Card FatFS Variables-----------------------------------------------------*/
FRESULT result; /* FatFs function common result code */
FILINFO fno;

FATFS *fs;
DWORD fre_clust, fre_sect, tot_sect;

BYTE work[_MAX_SS]; // for formatting SD

char *SD_Directory2;
int directory_lines=6;
char SD_space_description[150];

/* SPI Data transfer arrays ---------------------------------------------------------------*/
uint8_t SPI_input_buffer[DATABLOCK_SIZE];
uint8_t SPI_output_buffer[DATABLOCK_SIZE];

uint16_t SPI6_NCS;

/* WAV File--------------------------------------------------------------------*/
/*
 * Structure of Header and header variable
 */
typedef struct wavfile_header_s
{
	char    ChunkID[4];     /*  4   */
	uint32_t ChunkSize;      /*  4   */
	char    Format[4];      /*  4   */

	char    Subchunk1ID[4]; /*  4   */
	uint32_t Subchunk1Size;  /*  4   */
	uint16_t AudioFormat;    /*  2   */
	uint16_t NumChannels;    /*  2   */
	uint32_t SampleRate;     /*  4   */
	uint32_t ByteRate;       /*  4   */
	uint16_t BlockAlign;     /*  2   */
	uint16_t BitsPerSample;  /*  2   */

	char    Subchunk2ID[4];
	uint32_t Subchunk2Size;
} wavfile_header_t;

/* RTC Variables---------------------------------------------------------------*/
RTC_DateTypeDef gDate;
RTC_TimeTypeDef gTime;

/* USER CODE END PV */

void SystemClock_Config(void);
void PeriphCommonClock_Config(void);
static void MPU_Config(void);
static void MX_GPIO_Init(void);
static void MX_DMA_Init(void);
static void MX_MDMA_Init(void);
static void MX_ADC1_Init(void);
static void MX_RTC_Init(void);
static void MX_SDMMC1_SD_Init(void);
static void MX_UART4_Init(void);
static void MX_USART3_UART_Init(void);
static void MX_SPI6_Init(void);
/* USER CODE BEGIN PFP */
int send_to_raspi(uint8_t* dataBlock);
int read_from_raspi(uint8_t* dataBlock);
void datetime_request_handler(char* datablock);
void directory_request_handler();
FRESULT get_SD_directory (char* path);
void recording_request_handler();
int write_wav_header(int32_t SampleRate,int32_t FrameCount);
void delete_file_handler();
void transfer_request_handler();
void set_ADC_clock_prescalar(int sampling_fr);
/* USER CODE END PFP */

/**
  * @brief  The application entry point.
  * @retval int
  */
int main(void)
{

  /* USER CODE BEGIN 1 */
	/* ADC Testing and writing to SD Card*/
  /* USER CODE END 1 */

  /* MPU Configuration--------------------------------------------------------*/
  MPU_Config();

  /* MCU Configuration--------------------------------------------------------*/

  /* Reset of all peripherals, Initializes the Flash interface and the Systick. */
  HAL_Init();

  /* Configure the system clock */
  SystemClock_Config();

  /* Configure the peripherals common clocks */
  PeriphCommonClock_Config();

  /* Initialize all configured peripherals */
  MX_GPIO_Init();
  MX_DMA_Init();
  MX_MDMA_Init();
  MX_ADC1_Init();
  MX_RTC_Init();
  MX_SDMMC1_SD_Init();
  MX_UART4_Init();
  MX_USART3_UART_Init();
  MX_FATFS_Init();
  MX_SPI6_Init();
  /* USER CODE BEGIN 2 */
  int HAL_Status;
  const char delimiter[2] = ",";
  char *token;

	printf("\r\nProgram Start21\r\n");

	HAL_GPIO_WritePin(GAINB0_GPIO_Port, GAINB0_Pin, GPIO_PIN_SET);  /* Set get to 1 */
	HAL_GPIO_WritePin(GAINB1_GPIO_Port, GAINB1_Pin, GPIO_PIN_RESET);
	HAL_GPIO_WritePin(GAINB2_GPIO_Port, GAINB2_Pin, GPIO_PIN_RESET);

	// Let's check the file system and mount it
	f_mount(0, "", 0);
	HAL_Delay(500);
	if(f_mount(&SDFatFS, (TCHAR const*)SDPath, 0) != FR_OK)
	{
		printf("PANIC: Cannot mount SD Card\r\n");
		for(;;){}
	}

	HAL_GPIO_WritePin(Acq_Busy_GPIO_Port, Acq_Busy_Pin, GPIO_PIN_SET);  // Tell the RASPI we are Busy

	printf("\r\nLooping forever\r\n");
	for(;;){
		HAL_GPIO_WritePin(RED_LED_GPIO_Port, RED_LED_Pin, GPIO_PIN_RESET);

		do{
			HAL_Status = read_from_raspi(SPI_input_buffer);
		}
		while (HAL_Status != HAL_OK);
		HAL_GPIO_WritePin(RED_LED_GPIO_Port, RED_LED_Pin, GPIO_PIN_SET);
		token = strtok((char *)SPI_input_buffer, delimiter);

		printf("%s\r\n",token);
		if(strcmp(">DIR",token) == 0){
			printf("Doing Directory Command\r\n");
		    directory_request_handler();
		}
		else if(strcmp(">TIM",token) == 0){
			printf("Doing Date Time Command\r\n");
			datetime_request_handler(SPI_input_buffer);
		}

		else if(strcmp(">REC",token) == 0){
			printf("Doing Record Command\r\n");
			recording_request_handler();
		}

		else if(strcmp(">FMT",token) == 0){
			printf("Doing Format Command\r\n");
			result= f_mkfs("", FM_ANY, 0, work, sizeof(work));
			directory_lines=6;
		}

		else if(strcmp(">DEL",token) == 0){
			printf("Doing Delete File Command\r\n");
			delete_file_handler();
		}

		else if(strcmp(">XFR",token) == 0){
			printf("Doing Transfer File Command\r\n");
			transfer_request_handler();
		}


		else
			printf("Garbage Command\r\n");

	}

  /* USER CODE END 2 */

  /* Infinite loop */
  /* USER CODE BEGIN WHILE */
	while (1)
	{
    /* USER CODE END WHILE */

    /* USER CODE BEGIN 3 */
	}
  /* USER CODE END 3 */
}

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
/* USER CODE BEGIN 4 */
int _write(int file, char *ptr, int len)
{
	(void)file;
	int DataIdx;

	for (DataIdx = 0; DataIdx < len; DataIdx++)
	{
		HAL_UART_Transmit(&huart4,(uint8_t*)ptr++,1,1);// Sending in normal mode
	}
	return len;
}

void HAL_ADC_ConvHalfCpltCallback(ADC_HandleTypeDef* hadc)
{
	adc_lower_status = BUFFER_FULL;
	if(adc_upper_status == BUFFER_FULL)  // Overflow detect
	{
		HAL_GPIO_WritePin(GPIOB, Orange_LED_Pin, GPIO_PIN_SET);
		ADC_overrun=1; //Set overrun flag
	}
}

void HAL_ADC_ConvCpltCallback(ADC_HandleTypeDef* hadc)
{
	adc_upper_status = BUFFER_FULL;
	if(adc_lower_status == BUFFER_FULL)  // Overflow detect
	{
		HAL_GPIO_WritePin(GPIOB, Orange_LED_Pin, GPIO_PIN_SET);
		ADC_overrun=1; //Set overrun flag
	}
	//
}

int send_to_raspi(uint8_t* dataBlock)
{
	HAL_GPIO_WritePin(Acq_Busy_GPIO_Port, Acq_Busy_Pin, GPIO_PIN_RESET);  // Tell RASPI we are Ready
	int HAL_Status = HAL_SPI_Transmit(&hspi6, dataBlock, DATABLOCK_SIZE, 100);  // send DATABLOCK_SIZE bytes to the RASPI
	HAL_GPIO_WritePin(Acq_Busy_GPIO_Port, Acq_Busy_Pin, GPIO_PIN_SET);  // Tell the RASPI we are Busy
	return HAL_Status;
	}

int read_from_raspi(uint8_t* dataBlock)
{
	HAL_GPIO_WritePin(Acq_Busy_GPIO_Port, Acq_Busy_Pin, GPIO_PIN_RESET);  // Tell RASPI we are Ready
	int HAL_Status = HAL_SPI_Receive(&hspi6, dataBlock, DATABLOCK_SIZE, 1000);  // get DATABLOCK_SIZE bytes from the RASPI
	HAL_GPIO_WritePin(Acq_Busy_GPIO_Port, Acq_Busy_Pin, GPIO_PIN_SET);  // Tell the RASPI we are Busy
	return HAL_Status;
}

void directory_request_handler()
{
	char full_path_name[MAX_LENGTH_FILENAME];

	HAL_RTC_GetTime(&hrtc, &gTime, RTC_FORMAT_BIN);				/* Get the RTC current Date */
	HAL_RTC_GetDate(&hrtc, &gDate, RTC_FORMAT_BIN);				/* Display time Format: hh:mm:ss */
	printf("RTC Date Time  %02d:%02d:%02d  %02d-%02d-%2d\r\n",gTime.Hours, gTime.Minutes, gTime.Seconds,gDate.Month,gDate.Date,2000 + gDate.Year);				/* Display date Format: dd-mm-yy */

	/* allocate memory for directory listing */
	SD_Directory2 = malloc( 100 * directory_lines++ );

	if( SD_Directory2 == NULL ) {
		printf("PANIC: unable to allocate required memory\r\n");
	}
	/* Get volume information and free clusters of drive 1 */
	result = f_getfree("0:", &fre_clust, &fs);
	if (result!= FR_OK){
		printf("PANIC: unable to determine free space on SD\r\n");
	}
	/* Get total sectors and free sectors */
	tot_sect = (fs->n_fatent - 2) * fs->csize;
	fre_sect = fre_clust * fs->csize;
	/* Print free space in unit of KB (assuming 512 bytes/sector) */
	sprintf(SD_space_description,"%lu KB total drive space.     %lu KB available.\r\n",tot_sect / 2, fre_sect / 2);
	strcpy( SD_Directory2, SD_space_description);

	/* Get directory contents */
	strcpy(full_path_name, "/");

	result= get_SD_directory(full_path_name);
	//printf("%s", SD_Directory2);
	strcat( SD_Directory2, "\f");

	/* Send directory content to raspi */
	int buffer_index=0;
	do{
		SPI_output_buffer[buffer_index]= (uint8_t)SD_Directory2[buffer_index];
	}
	while(SD_Directory2[buffer_index++] != 12);
	send_to_raspi(SPI_output_buffer);

	printf("Directory Uploaded\r\n");
	free(SD_Directory2);
	directory_lines=5;

}

FRESULT get_SD_directory (char* path)        /* Start node to be scanned (***also used as work area***) */
{
	FRESULT res;
	DIR dir;
	UINT i;
	static FILINFO fno;
	char this_file[MAX_LENGTH_FILENAME];

	res = f_opendir(&dir, path);                       /* Open the directory */
	if (res == FR_OK) {
		for (;;) {
			res = f_readdir(&dir, &fno);                   /* Read a directory item */
			if (res != FR_OK || fno.fname[0] == 0) break;  /* Break on error or end of dir */
			if (fno.fattrib & AM_DIR) {                    /* It is a directory */
				i = strlen(path);
				sprintf(&path[i], "/%s", fno.fname);
				res = get_SD_directory(path);                    /* Enter the directory */
				if (res != FR_OK) break;
				path[i] = 0;
			} else {                                       /* It is a file. */
				sprintf(&this_file[0],"%s/%s\t%ld\t%u-%02u-%02u\t%02u:%02u\r\n", path, fno.fname,fno.fsize,(fno.fdate >> 9) + 1980, fno.fdate >> 5 & 15, fno.fdate & 31,fno.ftime >> 11, fno.ftime >> 5 & 63);
				SD_Directory2 = realloc(SD_Directory2, 100 * directory_lines++ );
				if( SD_Directory2 == NULL ) {
					printf("PANIC: unable to allocate required memory\r\n");
				} else {
					strcat( SD_Directory2, this_file);
				}
			}
		}
		f_closedir(&dir);
	}
	return res;
}
void datetime_request_handler(char* datablock ){
	const char delimiter[2] = ",";

	RTC_TimeTypeDef sTime;
	RTC_DateTypeDef sDate;

	sTime.Hours = (uint8_t)atoi(strtok(NULL, delimiter)); // set hours
	sTime.Minutes = (uint8_t)atoi(strtok(NULL, delimiter)); // set minutes
	sTime.Seconds = (uint8_t)atoi(strtok(NULL, delimiter)); // set seconds
	sTime.DayLightSaving = RTC_DAYLIGHTSAVING_NONE;
	sTime.StoreOperation = RTC_STOREOPERATION_RESET;
	if (HAL_RTC_SetTime(&hrtc, &sTime, RTC_FORMAT_BIN) != HAL_OK)
	{
		printf("FAIL: Problem setting time\r\n");
	}
	sDate.WeekDay = (uint8_t)atoi(strtok(NULL, delimiter));
	sDate.Month = (uint8_t)atoi(strtok(NULL, delimiter));
	sDate.Date = (uint8_t)atoi(strtok(NULL, delimiter)); // date
	sDate.Year = (uint8_t)atoi(strtok(NULL, delimiter)); // year
	if (HAL_RTC_SetDate(&hrtc, &sDate, RTC_FORMAT_BIN) != HAL_OK)
	{
		printf("FAIL: Problem setting date\r\n");
	}
	HAL_RTCEx_BKUPWrite(&hrtc, RTC_BKP_DR1, 0x32F2); // backup register
	printf("DateTime Set Complete\r\n");
}



void transfer_request_handler(){
	const char delimiter[2] = ",";
	char *file_to_be_transferred;
	file_to_be_transferred = strtok(NULL, delimiter);

	printf("opening file %s to transfer\r\n", file_to_be_transferred);
	if(f_open(&SDFile, file_to_be_transferred, FA_READ) != FR_OK)  				//Open file for reading and uploading
	{
		printf("FAIL: Cannot open file for reading uploading\r\n");
	}
	else
	{
		while(!f_eof(&SDFile)){
			result = f_read(&SDFile, SPI_output_buffer,DATABLOCK_SIZE, (void *)&bytes_read);
			if((bytes_read == 0) || (result != FR_OK))
			{
				printf("FAIL: Cannot read file to save upload\r\n");
			}
			else
			{
				send_to_raspi(SPI_output_buffer);
			}
		}
	    printf("%s Uploaded\r\n",file_to_be_transferred);
	}
	f_close(&SDFile);
}

void delete_file_handler(){
	const char delimiter[2] = ",";
	char *file_to_be_deleted;
	file_to_be_deleted = strtok(NULL, delimiter);

	printf("deleting file %s\r\n", file_to_be_deleted);
	if(f_unlink(file_to_be_deleted) != FR_OK)  				//delete file
	{
		printf("FAIL: Cannot delete file\r\n");
	}
	else{
		printf("%s Deleted\r\n",file_to_be_deleted);
	}
}


void recording_request_handler(){
	char fullfilename[MAX_LENGTH_FILENAME];

	HAL_RTC_GetTime(&hrtc, &gTime, RTC_FORMAT_BIN);				/* Get the RTC current Date */
	HAL_RTC_GetDate(&hrtc, &gDate, RTC_FORMAT_BIN);				/* Display time Format: hh:mm:ss */
	printf("RTC Date Time  %02d:%02d:%02d  %02d-%02d-%2d\r\n",gTime.Hours, gTime.Minutes, gTime.Seconds,gDate.Month,gDate.Date,2000 + gDate.Year);				/* Display date Format: dd-mm-yy */


	const char delimiter[2] = ",";
	char *file_to_be_recorded;
	int sampling_frequency_kHz = atoi(strtok(NULL, delimiter));
	int gain = atoi(strtok(NULL, delimiter));
	uint32_t millisecs_to_record = atoi(strtok(NULL, delimiter))*1000;
	file_to_be_recorded = strtok(NULL, delimiter);

	//HAL_GPIO_WritePin(GPIOC, GAINA0_Pin, gain & 0x01);      // Not setting gain for transducer preamp at this time
	//HAL_GPIO_WritePin(GPIOC, GAINA1_Pin, gain>>1 & 0x01);

	HAL_GPIO_WritePin(GPIOC, GAINB0_Pin, gain & 0x01);  // Set gain for onboard preamp
	HAL_GPIO_WritePin(GPIOC, GAINB1_Pin, gain>>1 & 0x01);
	HAL_GPIO_WritePin(GPIOC, GAINB2_Pin, gain>>2 & 0x01);

	HAL_GPIO_WritePin(GPIOB, Orange_LED_Pin, GPIO_PIN_RESET);  // Clear overrun LED

	printf("Record: Sampling %3dkHz  Gain %1d   Duration %lumS  %s \r\n", sampling_frequency_kHz, gain, millisecs_to_record,file_to_be_recorded);

	if(f_open(&SDFile, file_to_be_recorded, FA_CREATE_ALWAYS | FA_WRITE) != FR_OK)  //Open file for writing (Create)
	{
		printf("FAIL: Cannot open file for recording\r\n");
	}
	else
	{
		write_wav_header(sampling_frequency_kHz*1000,sampling_frequency_kHz*millisecs_to_record); 							// Write WAV Header Sampling at 786000 Hz
		for(adcbuf_index=0;adcbuf_index < ADCBUFLEN;adcbuf_index++) // Clear ADC Buffer
		{
			adc_buf[adcbuf_index]=0;
		}
		total_blocks_written=0;
		total_bytes_written=0;
		adc_lower_status = BUFFER_EMPTY;
		adc_upper_status = BUFFER_EMPTY;
		overrun_count=0;
		max_save_time_ms=0;
		//HAL_GPIO_WritePin(RED_LED_GPIO_Port, RED_LED_Pin, GPIO_PIN_RESET);
		set_ADC_clock_prescalar(sampling_frequency_kHz);
		HAL_ADC_Start_DMA(&hadc1, (uint32_t*)adc_buf, ADCBUFLEN); 	// Enable ADC DMA and add contents
		end_acq_ms=uwTick+millisecs_to_record;
		do{
			if(adc_lower_status == BUFFER_FULL)
			{
				HAL_GPIO_WritePin(GPIOE, RecordEnable_Pin, GPIO_PIN_RESET);
				start_time_ms=uwTick;
				f_write(&SDFile, &adc_buf[0], ADCBUFLEN, (void *)&bytes_written);
				ms_taken=uwTick-start_time_ms;
				if(ms_taken > max_save_time_ms){
					max_save_time_ms = ms_taken;
				}
				total_bytes_written = total_bytes_written+bytes_written;
				adc_lower_status = BUFFER_EMPTY;
				total_blocks_written++;
				if(ADC_overrun){
					HAL_ADC_Stop_DMA(&hadc1);
					f_write(&SDFile, &adc_buf[ADCBUFLEN/2], ADCBUFLEN, (void *)&bytes_written);
					total_bytes_written = total_bytes_written+bytes_written;
					adc_upper_status = BUFFER_EMPTY;
					total_blocks_written++;
					ADC_overrun=0;
					overrun_count++;
					HAL_ADC_Start_DMA(&hadc1, (uint32_t*)adc_buf, ADCBUFLEN); 	// Enable ADC DMA and add contents
				}
			}
			if(adc_upper_status == BUFFER_FULL)
			{
				HAL_GPIO_WritePin(GPIOE, RecordEnable_Pin, GPIO_PIN_SET);
				start_time_ms=uwTick;
				f_write(&SDFile, &adc_buf[ADCBUFLEN/2], ADCBUFLEN, (void *)&bytes_written);
				ms_taken=uwTick-start_time_ms;
				if(ms_taken > max_save_time_ms){
					max_save_time_ms = ms_taken;
				}
				total_bytes_written = total_bytes_written+bytes_written;
				adc_upper_status = BUFFER_EMPTY;
				total_blocks_written++;
				if(ADC_overrun){
					HAL_ADC_Stop_DMA(&hadc1);
					f_write(&SDFile, &adc_buf[0], ADCBUFLEN, (void *)&bytes_written);
					total_bytes_written = total_bytes_written+bytes_written;
					adc_lower_status = BUFFER_EMPTY;
					total_blocks_written++;
					ADC_overrun=0;
					overrun_count++;
					HAL_ADC_Start_DMA(&hadc1, (uint32_t*)adc_buf, ADCBUFLEN); 	// Enable ADC DMA and add contents
				}
			}
		}
		while(uwTick< end_acq_ms);
		HAL_ADC_Stop_DMA(&hadc1);   								// Halt ADC DMA

		// Now update WAV file with data length
		f_lseek(&SDFile,0x28);
		f_write(&SDFile,&total_bytes_written, 4, (void *)&bytes_written);

		f_close(&SDFile);  											// Writing complete so close file
		printf("Total Blocks Written %lu  Total Bytes Written %lu MaxSaveTime %d  Overruns %d\r\n",total_blocks_written,total_bytes_written,max_save_time_ms,overrun_count);
		printf("Recording Complete\r\n");

		strcpy(fullfilename,"//");
		strcat(fullfilename,file_to_be_recorded);
		HAL_RTC_GetTime(&hrtc, &gTime, RTC_FORMAT_BIN);				/* Get the RTC current Date */
		HAL_RTC_GetDate(&hrtc, &gDate, RTC_FORMAT_BIN);				/* Display time Format: hh:mm:ss */
		fno.fdate = (WORD)(((gDate.Year+20) * 512U) | gDate.Month * 32U | gDate.Date);
		fno.ftime = (WORD)(gTime.Hours * 2048U | gTime.Minutes * 32U | gTime.Seconds / 2U);
		result=f_utime(fullfilename, &fno);
	}
}

/*
 * Function to write header of WAV file
 */
/*Return 0 on success and -1 on failure*/
int write_wav_header(int32_t SampleRate,int32_t FrameCount)
{
	int ret=0;

	struct wavfile_header_s wav_header;
	int32_t subchunk2_size;
	int32_t chunk_size;

	//    size_t write_count;

	uint32_t bytes_written=0;

	FRESULT result; /* FatFs function common result code */

	subchunk2_size  = FrameCount * NUM_CHANNELS * BITS_PER_SAMPLE / 8;
	chunk_size      = 4 + (8 + SUBCHUNK1SIZE) + (8 + subchunk2_size);

	wav_header.ChunkID[0] = 'R';
	wav_header.ChunkID[1] = 'I';
	wav_header.ChunkID[2] = 'F';
	wav_header.ChunkID[3] = 'F';

	wav_header.ChunkSize = chunk_size;

	wav_header.Format[0] = 'W';
	wav_header.Format[1] = 'A';
	wav_header.Format[2] = 'V';
	wav_header.Format[3] = 'E';

	wav_header.Subchunk1ID[0] = 'f';
	wav_header.Subchunk1ID[1] = 'm';
	wav_header.Subchunk1ID[2] = 't';
	wav_header.Subchunk1ID[3] = ' ';

	wav_header.Subchunk1Size = SUBCHUNK1SIZE;
	wav_header.AudioFormat = AUDIO_FORMAT;
	wav_header.NumChannels = NUM_CHANNELS;
	wav_header.SampleRate = SampleRate;
	wav_header.ByteRate = SampleRate <<1;
	wav_header.BlockAlign = BLOCK_ALIGN;
	wav_header.BitsPerSample = BITS_PER_SAMPLE;

	wav_header.Subchunk2ID[0] = 'd';
	wav_header.Subchunk2ID[1] = 'a';
	wav_header.Subchunk2ID[2] = 't';
	wav_header.Subchunk2ID[3] = 'a';
	wav_header.Subchunk2Size = subchunk2_size;

	printf("chunk_size %ld %lx\r\n", chunk_size,chunk_size);
	printf("subchunk2_size %ld %lx\r\n", subchunk2_size,subchunk2_size);
	//Open file for writing (Create)
	result = f_write(&SDFile, &wav_header, sizeof(wavfile_header_t), (void *)&bytes_written);
	if((bytes_written == 0) || (result != FR_OK))
	{
		Error_Handler();
	}

	// Flush the file buffers
	result = f_sync(&SDFile);
	if(result != FR_OK)
	{
		Error_Handler();
	}
	return ret;
}

void set_ADC_clock_prescalar(int sampling_fr){
	ADC_MultiModeTypeDef multimode = {0};
	switch(sampling_fr){
	case 800:
		hadc1.Init.ClockPrescaler = ADC_CLOCK_ASYNC_DIV4;
		break;
	case 533:
		hadc1.Init.ClockPrescaler = ADC_CLOCK_ASYNC_DIV6;
		break;
	case 400:
		hadc1.Init.ClockPrescaler = ADC_CLOCK_ASYNC_DIV8;
		break;
	case 320:
		hadc1.Init.ClockPrescaler = ADC_CLOCK_ASYNC_DIV10;
		break;
	case 266:
		hadc1.Init.ClockPrescaler = ADC_CLOCK_ASYNC_DIV12;
		break;
	case 200:
		hadc1.Init.ClockPrescaler = ADC_CLOCK_ASYNC_DIV16;
		break;
	case 100:
		hadc1.Init.ClockPrescaler = ADC_CLOCK_ASYNC_DIV32;
		break;
	case 50:
		hadc1.Init.ClockPrescaler = ADC_CLOCK_ASYNC_DIV64;
		break;
	case 25:
		hadc1.Init.ClockPrescaler = ADC_CLOCK_ASYNC_DIV128;
		break;
	case 12:
		hadc1.Init.ClockPrescaler = ADC_CLOCK_ASYNC_DIV256;
		break;
	}
	if (HAL_ADC_Init(&hadc1) != HAL_OK)
	{
		Error_Handler();
	}

	/** Configure the ADC multi-mode
	 */
	multimode.Mode = ADC_MODE_INDEPENDENT;
	if (HAL_ADCEx_MultiModeConfigChannel(&hadc1, &multimode) != HAL_OK)
	{
		Error_Handler();
	}

}



/* USER CODE END 4 */

 /* MPU Configuration */

void MPU_Config(void)
{
  MPU_Region_InitTypeDef MPU_InitStruct = {0};

  /* Disables the MPU */
  HAL_MPU_Disable();

  /** Initializes and configures the Region and the memory to be protected
  */
  MPU_InitStruct.Enable = MPU_REGION_ENABLE;
  MPU_InitStruct.Number = MPU_REGION_NUMBER0;
  MPU_InitStruct.BaseAddress = 0x0;
  MPU_InitStruct.Size = MPU_REGION_SIZE_4GB;
  MPU_InitStruct.SubRegionDisable = 0x87;
  MPU_InitStruct.TypeExtField = MPU_TEX_LEVEL0;
  MPU_InitStruct.AccessPermission = MPU_REGION_NO_ACCESS;
  MPU_InitStruct.DisableExec = MPU_INSTRUCTION_ACCESS_DISABLE;
  MPU_InitStruct.IsShareable = MPU_ACCESS_SHAREABLE;
  MPU_InitStruct.IsCacheable = MPU_ACCESS_NOT_CACHEABLE;
  MPU_InitStruct.IsBufferable = MPU_ACCESS_NOT_BUFFERABLE;

  HAL_MPU_ConfigRegion(&MPU_InitStruct);
  /* Enables the MPU */
  HAL_MPU_Enable(MPU_PRIVILEGED_DEFAULT);

}

/**
  * @brief  This function is executed in case of error occurrence.
  * @retval None
  */
void Error_Handler(void)
{
  /* USER CODE BEGIN Error_Handler_Debug */
	/* User can add his own implementation to report the HAL error return state */
	__disable_irq();
	while (1)
	{
	}
  /* USER CODE END Error_Handler_Debug */
}
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

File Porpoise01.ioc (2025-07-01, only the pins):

Mcu.UserName=STM32H725VGTx
PA0.GPIO_Label=SD_Card_Detect
PA0.Signal=GPIO_Input
PA4.Signal=SPI6_NSS
PA5.Signal=SPI6_SCK
PA6.Signal=SPI6_MISO
PA7.Signal=SPI6_MOSI
PB0.Signal=ADCx_INN5
PB1.Signal=ADCx_INP5
PB13.Signal=SDMMC1_D0
PB5.GPIO_Label=RED_LED
PB5.Signal=GPIO_Output
PB6.GPIO_Label=Orange_LED
PB6.Signal=GPIO_Output
PC10.Signal=SDMMC1_D2
PC11.Signal=SDMMC1_D3
PC12.Signal=SDMMC1_CK
PC14-OSC32_IN.Signal=RCC_OSC32_IN
PC15-OSC32_OUT.Signal=RCC_OSC32_OUT
PC6.GPIO_Label=GAINB0
PC6.Signal=GPIO_Output
PC7.GPIO_Label=GAINB1
PC7.Signal=GPIO_Output
PC8.GPIO_Label=GAINB2
PC8.Signal=GPIO_Output
PC9.Signal=SDMMC1_D1
PD0.Signal=UART4_RX
PD1.Signal=UART4_TX
PD10.GPIO_Label=GAINA0
PD10.Signal=GPIO_Output
PD11.GPIO_Label=GAINA1
PD11.Signal=GPIO_Output
PD2.Signal=SDMMC1_CMD
PD8.Signal=USART3_TX
PD9.Signal=USART3_RX
PE7.GPIO_Label=RecordEnable
PE7.Signal=GPIO_Output
PE8.GPIO_Label=Acq_Busy
PE8.Signal=GPIO_Output
PH0-OSC_IN.Signal=RCC_OSC_IN
PH1-OSC_OUT.Signal=RCC_OSC_OUT

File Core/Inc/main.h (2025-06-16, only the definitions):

#define SD_Card_Detect_Pin GPIO_PIN_0
#define SD_Card_Detect_GPIO_Port GPIOA
#define Record_Enable_Pin GPIO_PIN_7
#define Record_Enable_GPIO_Port GPIOE
#define Acq_Busy_Pin GPIO_PIN_8
#define Acq_Busy_GPIO_Port GPIOE
#define GAINA0_Pin GPIO_PIN_10
#define GAINA0_GPIO_Port GPIOD
#define GAINA1_Pin GPIO_PIN_11
#define GAINA1_GPIO_Port GPIOD
#define GAINB0_Pin GPIO_PIN_6
#define GAINB0_GPIO_Port GPIOC
#define GAINB1_Pin GPIO_PIN_7
#define GAINB1_GPIO_Port GPIOC
#define GAINB2_Pin GPIO_PIN_8
#define GAINB2_GPIO_Port GPIOC
#define RED_LED_Pin GPIO_PIN_5
#define RED_LED_GPIO_Port GPIOB

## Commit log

2025-06-22 Gain setup x1 with UART4 debug working
2025-06-29 SPI6 Support
    SPI operating at a basic level. Receiving commands from raspi in form of >TIM for example. Sets time correctly and can initiate a directory request (but not process yet)
    [main.c]
2025-06-30 Works with 6/29/2025 main software
    This IOC supports SD card, UART4, SPI6. It is configured for the ADC but not tests
2025-06-30 Create UAserver.py
    This works with the porpoise01. It can set the date/time and get the directory list. It does not yet support the ADC/Acquisition and also does not control the gain of the porpoise 01 or of the pre-amp
2025-06-30 Onboard amplifier gain support
    Now correctly sets gain based in B0,B1,B2.
    [main.c]
2025-07-01 Support for continuous DMA
    Now supports acquisition and data transfer to pi
2025-07-01 LED support for download transaction
    One LED shows command download from Pi and One LED for ADC overrun. Using Record Enable pin to report when ADC buffer is full/switched (used to check ADC convert rate)
2025-07-09 Raspberry Pi
    [config.cfg]
2025-11-06 Add initial Kicad files list
2025-11-06 kiCad files for whaleboard
    [af_input.kicad_sch, input.kicad_sch, micro.kicad_sch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]

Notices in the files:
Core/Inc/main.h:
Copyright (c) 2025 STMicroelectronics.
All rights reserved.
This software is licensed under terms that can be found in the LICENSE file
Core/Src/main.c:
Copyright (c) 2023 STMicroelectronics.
